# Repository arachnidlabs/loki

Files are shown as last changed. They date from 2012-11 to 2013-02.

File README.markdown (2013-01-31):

Loki
====

Loki is a flexible development platform based on Cypress's PSoC 5 line of processors.

For much more about Loki, check out the [Arachnid Labs Blog](http://www.arachnidlabs.com/)

All the Loki source and schematics are open hardware and OSS, and licensed under the [BSD 2-clause license](http://opensource.org/licenses/BSD-2-Clause). Reuse and remix as you see fit!

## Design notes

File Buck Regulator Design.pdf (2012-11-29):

## WEBENCH ® Design Report

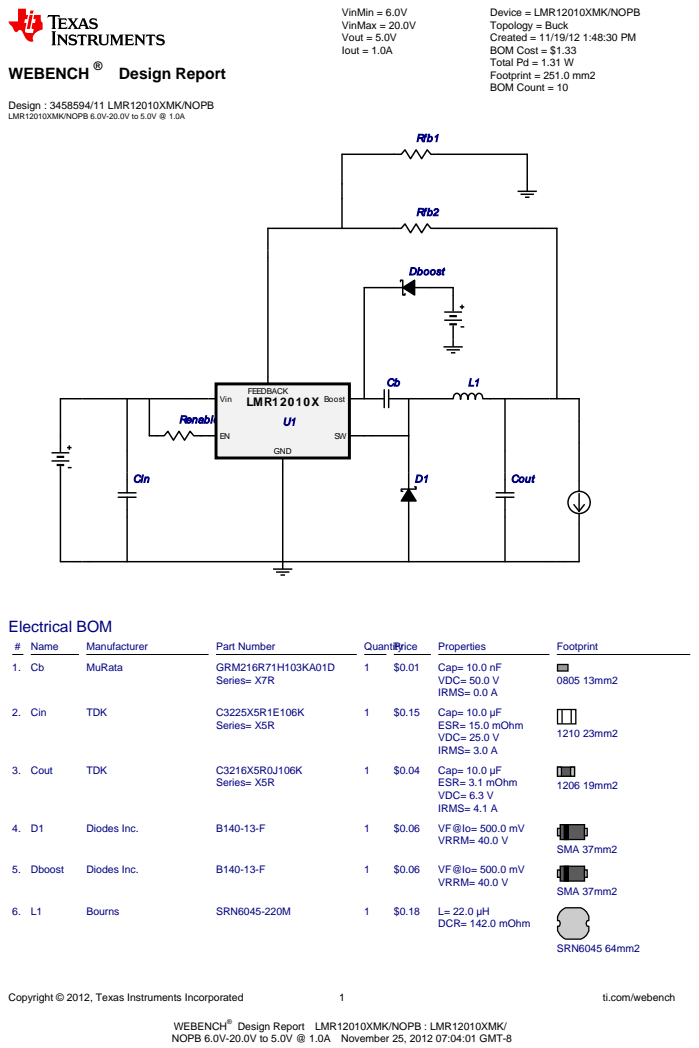
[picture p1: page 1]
Copyright © 2012, Texas Instruments Incorporated; ti.com/webench; Design : 3458594/11 LMR12010XMK/NOPB LMR12010XMK/NOPB 6.0V-20.0V to 5.0V @ 1.0A; VinMin = 6.0V VinMax = 20.0V Vout = 5.0V Iout = 1.0A; Device = LMR12010XMK/NOPB Topology = Buck Created = 11/19/12 1:48:30 PM BOM Cost = $1.33 Total Pd = 1.31 W Footprint = 251.0 mm2 BOM Count = 10; Cin; Cout; Dboost; Renable; LMR12010X; FEEDBACK; Vin; Boost; GND; Rfb1; Rfb2; Electrical BOM; # Name; Manufacturer; Part Number; QuantityPrice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

WEBENCH®
NOPB 6.0V-20.0V to 5.0V @ 1.0A November 25, 2012 07:04:01 GMT-8

Design Report LMR12010XMK/NOPB : LMR12010XMK/

Design

Copyright © 2012, Texas Instruments Incorporated | 2 | ti.com/webench
# Name | Manufacturer | Part Number | QuantityPrice | Properties | Footprint

7. Renable | Vishay-Dale | CRCW080510K0FKEA (http://www.vishay.com/docs/20035/dcrcwe3.pdf)
Series= CRCW..e3
1 | $0.01 | Res= 10.0 kOhm
Power= 125.0 mW
Tolerance= 1.0%

0805 13mm2

8. Rfb1 | Vishay-Dale | CRCW080510K0FKEA (http://www.vishay.com/docs/20035/dcrcwe3.pdf)
Series= CRCW..e3
1 | $0.01 | Res= 10.0 kOhm
Power= 125.0 mW
Tolerance= 1.0%

0805 13mm2

9. Rfb2 | Vishay-Dale | CRCW080552K3FKEA (http://www.vishay.com/docs/20035/dcrcwe3.pdf)
Series= CRCW..e3
1 | $0.01 | Res= 52.3 kOhm
Power= 125.0 mW
Tolerance= 1.0%

0805 13mm2

10. U1 | Texas Instruments | LMR12010XMK/NOPB (http://www.ti.com/product/lmr12010) | 1 | $0.80 | Switcher

MK06A 18mm2

## Operating Values

# | Name | Value | Category | Description

1. BOM Count | 10.0 | Total Design BOM count
2. Total BOM | $1.33 | Total BOM Cost
3. Cin IRMS | 444.634 m A | Current | Input capacitor RMS ripple current
4. Cout IRMS | 33.375 m A | Current | Output capacitor RMS ripple current
5. IC Ipk | 1.058 A | Current | Peak switch current in IC
6. Iin Avg | 315.61 m A | Current | Average input current
7. L Ipp | 115.614 m A | Current | Peak-to-peak inductor ripple current
8. M1 Irms | 520.872 m A | Current | Q Iavg
9. FootPrint | 251.0 mm2 | General | Total Foot Print Area of BOM components
10. Frequency | 1.6 M Hz | General | Switching frequency
11. IC Tolerance | 16.0 m V | General | IC Feedback Tolerance
12. M Vds Act | 227.775 m V | General
13. Mode | CCM | General | Conduction Mode
14. Pout | 5.0 W | General | Total output power
15. Duty Cycle | 27.131 % | Op_point | Duty cycle
16. Efficiency | 79.212 % | Op_point | Steady state efficiency
17. IC Tj | 123.059 degC | Op_point | IC junction temperature
18. ICThetaJA | 118.0 degC/W | Op_point | IC junction-to-ambient thermal resistance
19. IOUT_OP | 1.0 A | Op_point | Iout operating point
20. VIN_OP | 20.0 V | Op_point | Vin operating point
21. Vout p-p | 971.742 µ V | Op_point | Peak-to-peak output ripple voltage
22. Cin Pd | 2.965 m W | Power | Input capacitor power dissipation
23. Cout Pd | 3.453 µ W | Power | Output capacitor power dissipation
24. Diode Pd | 364.346 m W | Power | Diode power dissipation
25. IC Pd | 788.638 m W | Power | IC power dissipation
26. L Pd | 156.2 m W | Power | Inductor power dissipation
27. Total Pd | 1.312 W | Power | Total Power Dissipation

## Design Inputs

# | Name | Value | Description

1. Iout | 1.0 A | Maximum Output Current
2. Iout1 | 1.0 Amps | Output Current #1
3. VinMax | 20.0 V | Maximum input voltage
4. VinMin | 6.0 V | Minimum input voltage
5. Vout | 5.0 V | Output Voltage
6. Vout1 | 5.0 Volt | Output Voltage #1
7. base_pn | LMR12010X | National Based Product Number
8. Ta | 30.0 degC | Ambient temperature

## Design Assistance

1. LMR12010X Product Folder : http://www.ti.com/product/lmr12010 : contains the data sheet and other resources.

Design

Copyright © 2012, Texas Instruments Incorporated | 3 | ti.com/webench

Texas Instruments' WEBENCH simulation tools attempt to recreate the performance of a substantially equivalent physical implementation
of the design. Simulations are created using Texas Instruments' published specifications as well as the published specifications of other device manufacturers. While Texas Instruments does update this information periodically, this information may not be current at the time the simulation is built. Texas Instruments does not warrant the accuracy or completeness of the specifications or any information contained therein. Texas Instruments does not warrant that any designs or recommended parts will meet the specifications you entered, will be suitable for your application or fit for any particular purpose, or will operate as shown in the simulation in a physical implementation. Texas Instruments does not warrant that the designs are production worthy.
You should completely validate and test your design implementation to confirm the system functionality for your application prior to production.
Use of Texas Instruments' WEBENCH simulation tools is subject to Texas Instruments' Site Terms and Conditions of Use. (http://www.ti.com/corp/docs/legal/termsofuse.shtml) Prototype boards based on WEBENCH created designs are provided AS IS without warranty of any kind for evaluation and testing purposes and are subject to the terms of the Evaluation License Agreement. (http://www.ti.com/corp/docs/legal/termsofuse_estore.shtml)

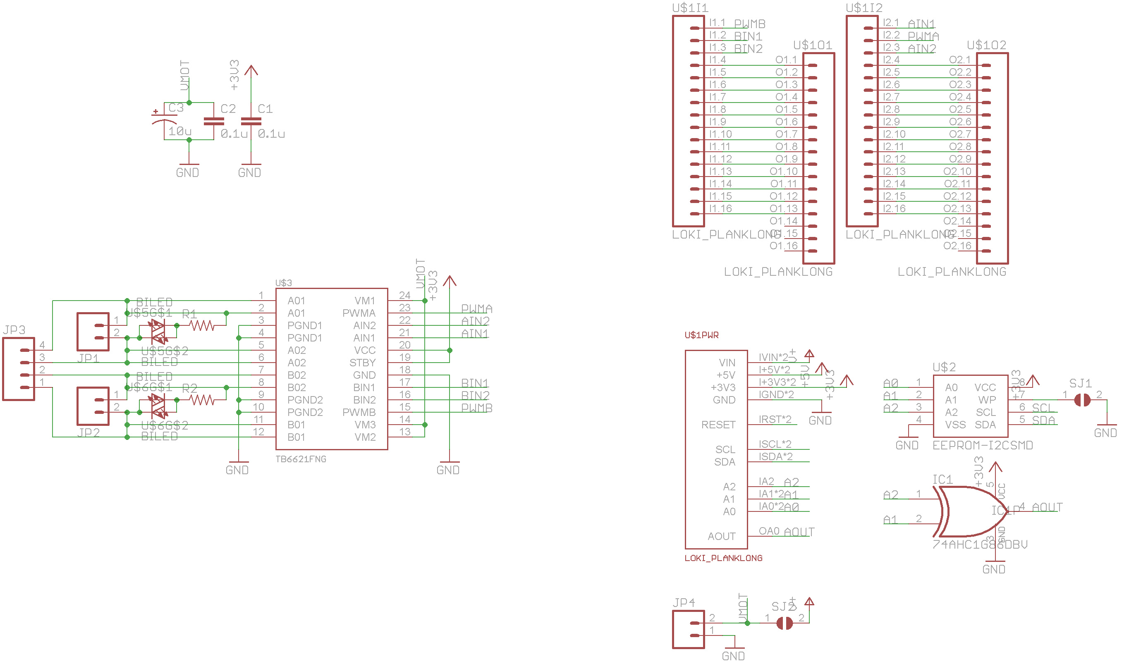
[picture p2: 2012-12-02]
schematics/motorplank/motorplank-schematic.png

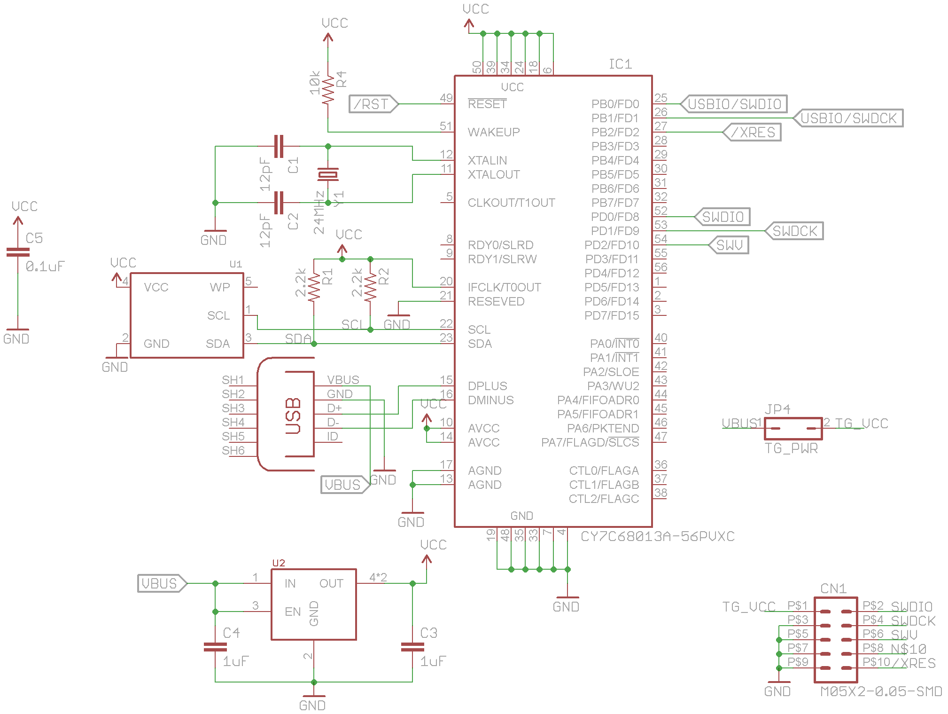
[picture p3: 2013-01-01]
schematics/programmer/programmer-schematic.png

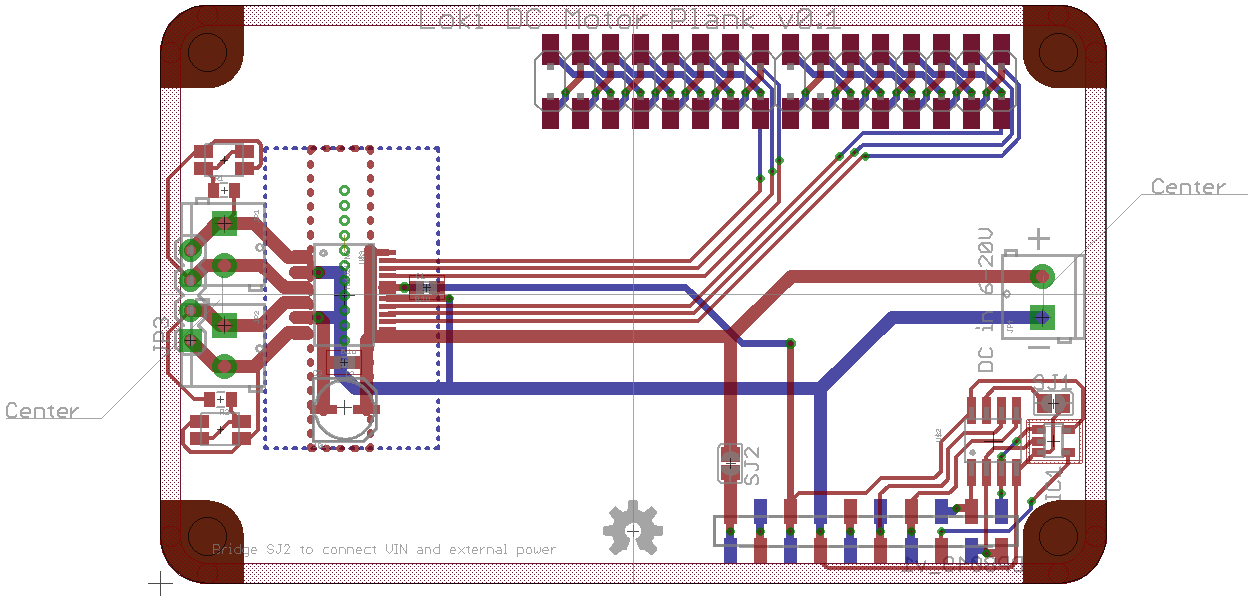
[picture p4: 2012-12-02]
schematics/motorplank/motorplank-layout.png

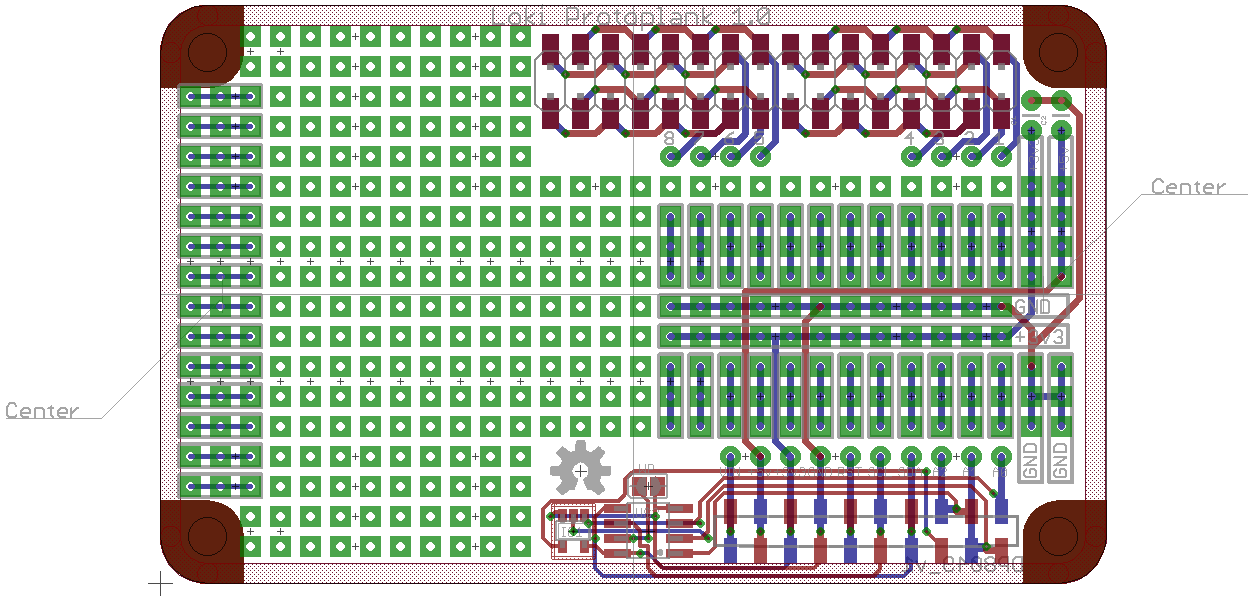
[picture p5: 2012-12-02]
schematics/protoplank/protoplank-layout.png

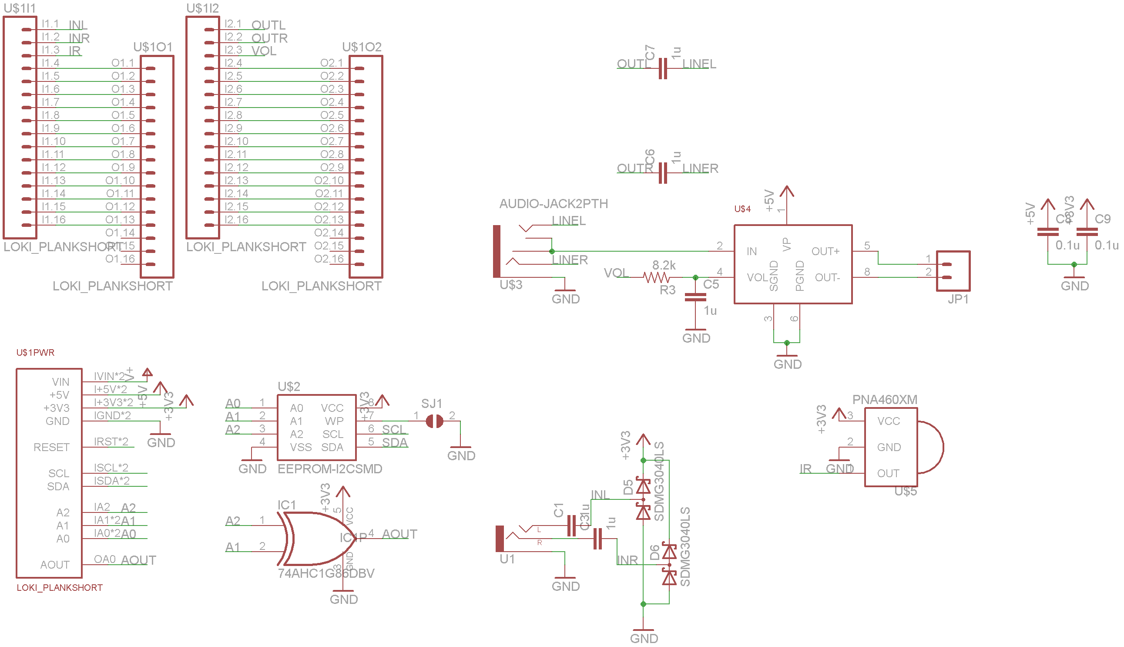
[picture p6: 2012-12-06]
schematics/soundplank/soundplank-schematic.png

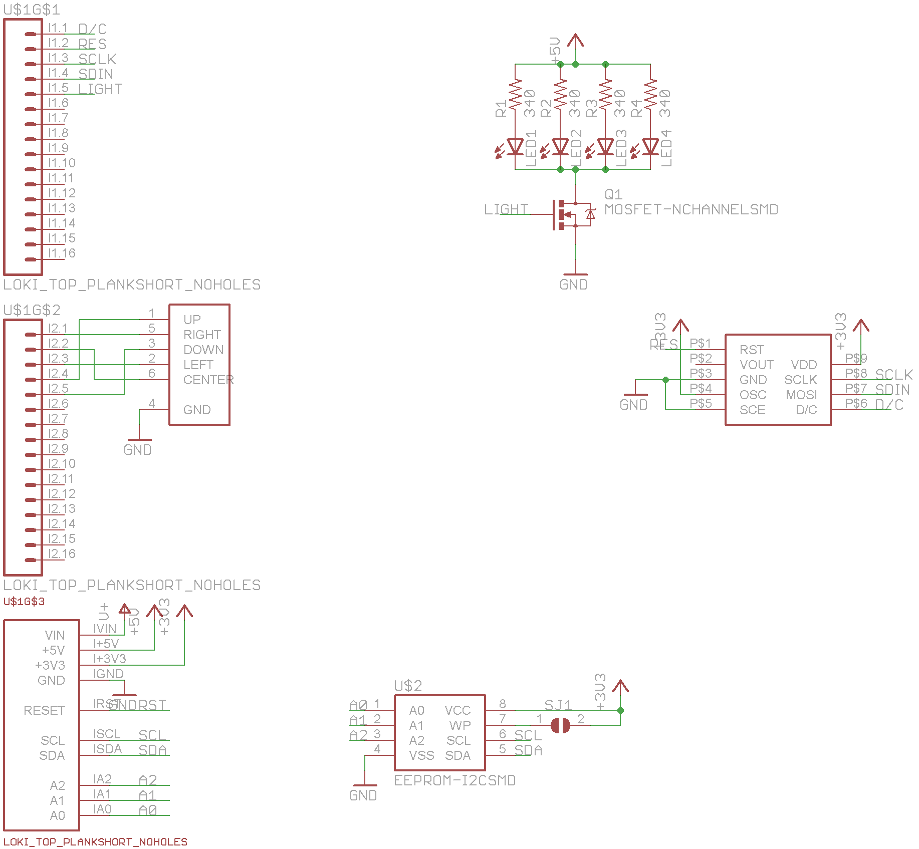
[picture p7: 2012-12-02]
schematics/displayplank/displayplank-schematic.png

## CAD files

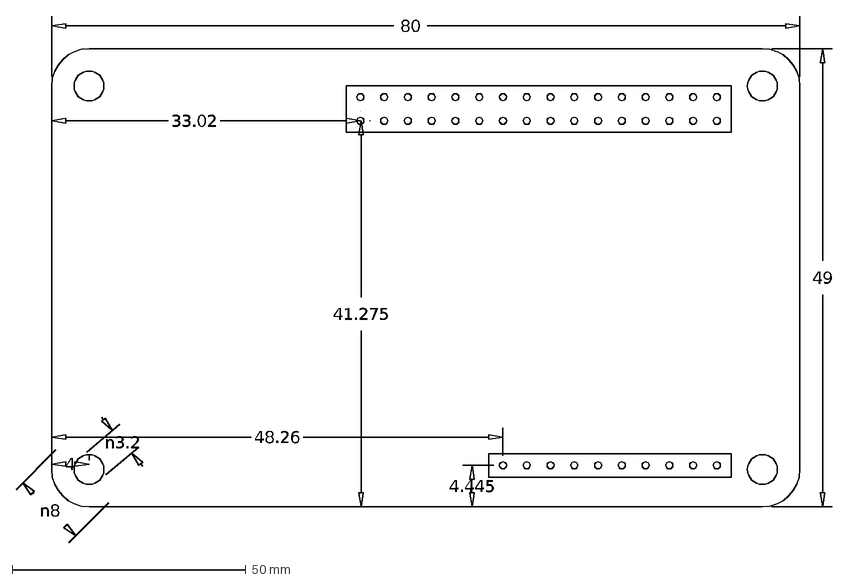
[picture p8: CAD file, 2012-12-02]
drawings/Dimensional Drawing.dxf
80
49
33.02
41.275
4.445
48.26
4

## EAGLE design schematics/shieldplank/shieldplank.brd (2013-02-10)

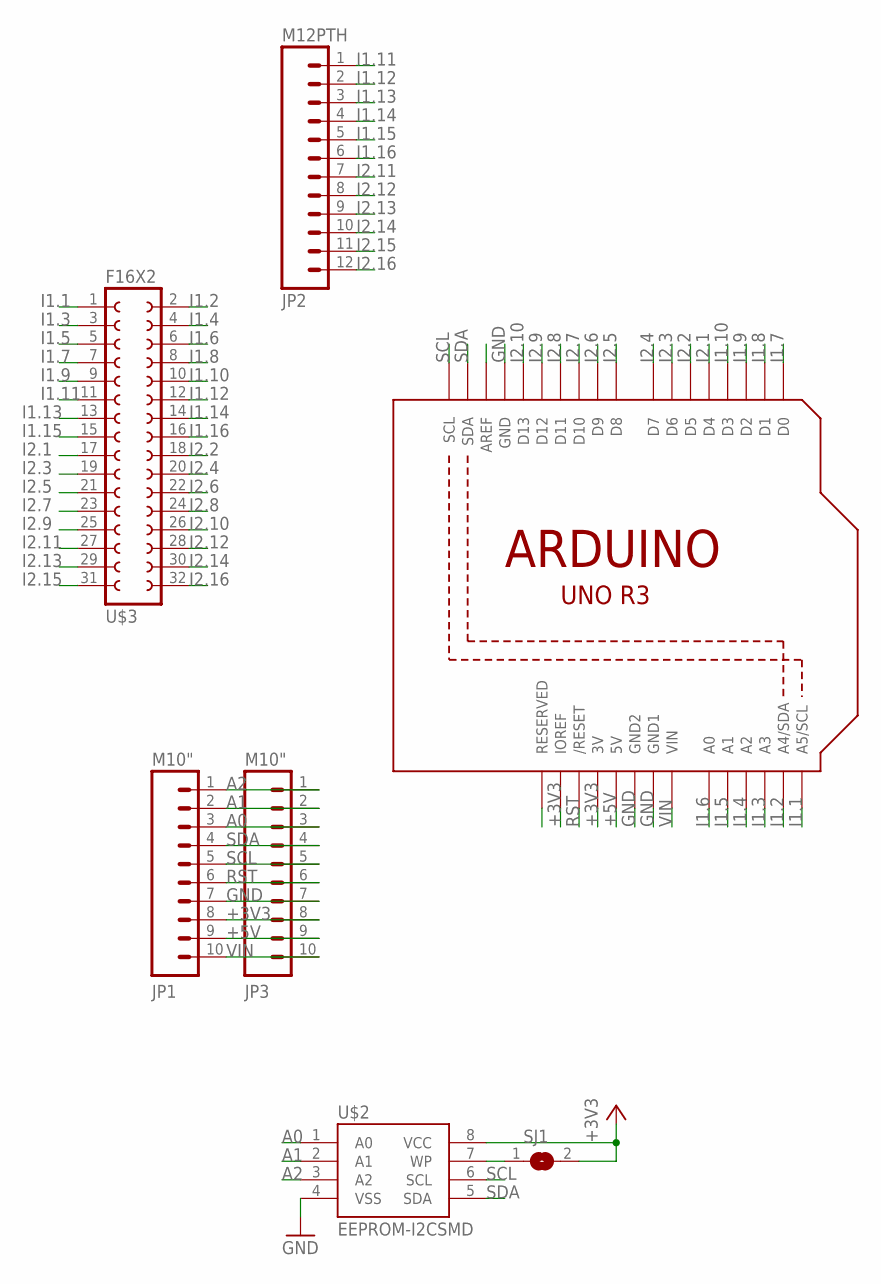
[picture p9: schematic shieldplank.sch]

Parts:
JP1, JP3: M10"; 1X10
JP2: M12PTH; 1X12
SJ1: SJ
U1: ARDUINOR3-BPLACE
U$2: EEPROM-I2CSMD; SO08
U$3: F16X2; FE16-2

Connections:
+3V3: JP1.8, JP3.8, SJ1.2, U1.3V, U1.IOREF, U$2.8 (VCC)
+5V: JP1.9, JP3.9, U1.5V
A0: JP1.3, JP3.3, U$2.1 (A0)
A1: JP1.2, JP3.2, U$2.2 (A1)
A2: JP1.1, JP3.1, U$2.3 (A2)
GND: JP1.7, JP3.7, U1.GND, U1.GND1, U1.GND2, U$2.4 (VSS)
I1.1: U1.A5 (A5/SCL), U$3.1
I1.2: U1.A4 (A4/SDA), U$3.2
I1.3: U1.A3, U$3.3
I1.4: U1.A2, U$3.4
I1.5: U1.A1, U$3.5
I1.6: U1.A0, U$3.6
I1.7: U1.D0, U$3.7
I1.8: U1.D1, U$3.8
I1.9: U1.D2, U$3.9
I1.10: U1.D3, U$3.10
I1.11: JP2.1, U$3.11
I1.12: JP2.2, U$3.12
I1.13: JP2.3, U$3.13
I1.14: JP2.4, U$3.14
I1.15: JP2.5, U$3.15
I1.16: JP2.6, U$3.16
I2.1: U1.D4, U$3.17
I2.2: U1.D5, U$3.18
I2.3: U1.D6, U$3.19
I2.4: U1.D7, U$3.20
I2.5: U1.D8, U$3.21
I2.6: U1.D9, U$3.22
I2.7: U1.D10, U$3.23
I2.8: U1.D11, U$3.24
I2.9: U1.D12, U$3.25
I2.10: U1.D13, U$3.26
I2.11: JP2.7, U$3.27
I2.12: JP2.8, U$3.28
I2.13: JP2.9, U$3.29
I2.14: JP2.10, U$3.30
I2.15: JP2.11, U$3.31
I2.16: JP2.12, U$3.32
unnamed: SJ1.1, U$2.7 (WP)
RST: JP1.6, JP3.6, U1.RESET (/RESET)
SCL: JP1.5, JP3.5, U1.SCL, U$2.6 (SCL)
SDA: JP1.4, JP3.4, U1.SDA, U$2.5 (SDA)
VIN: JP1.10, JP3.10, U1.VIN

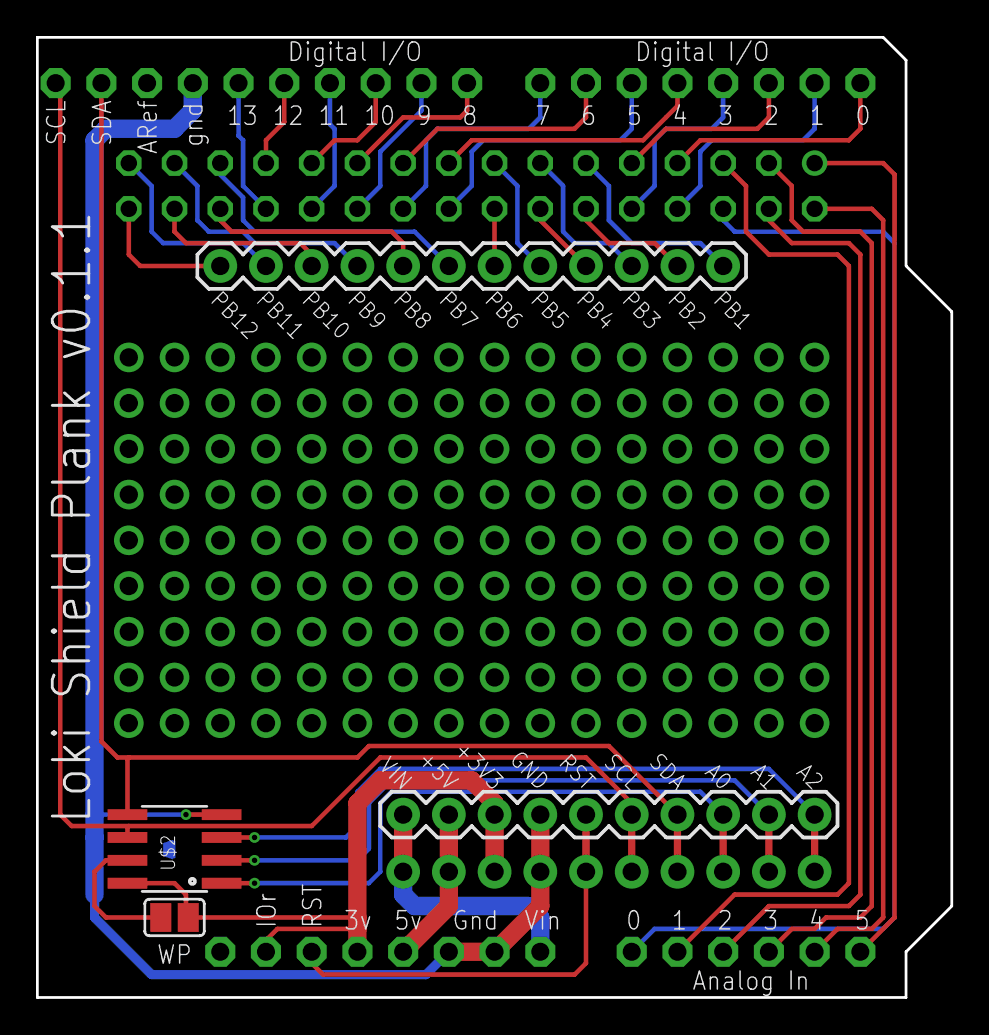
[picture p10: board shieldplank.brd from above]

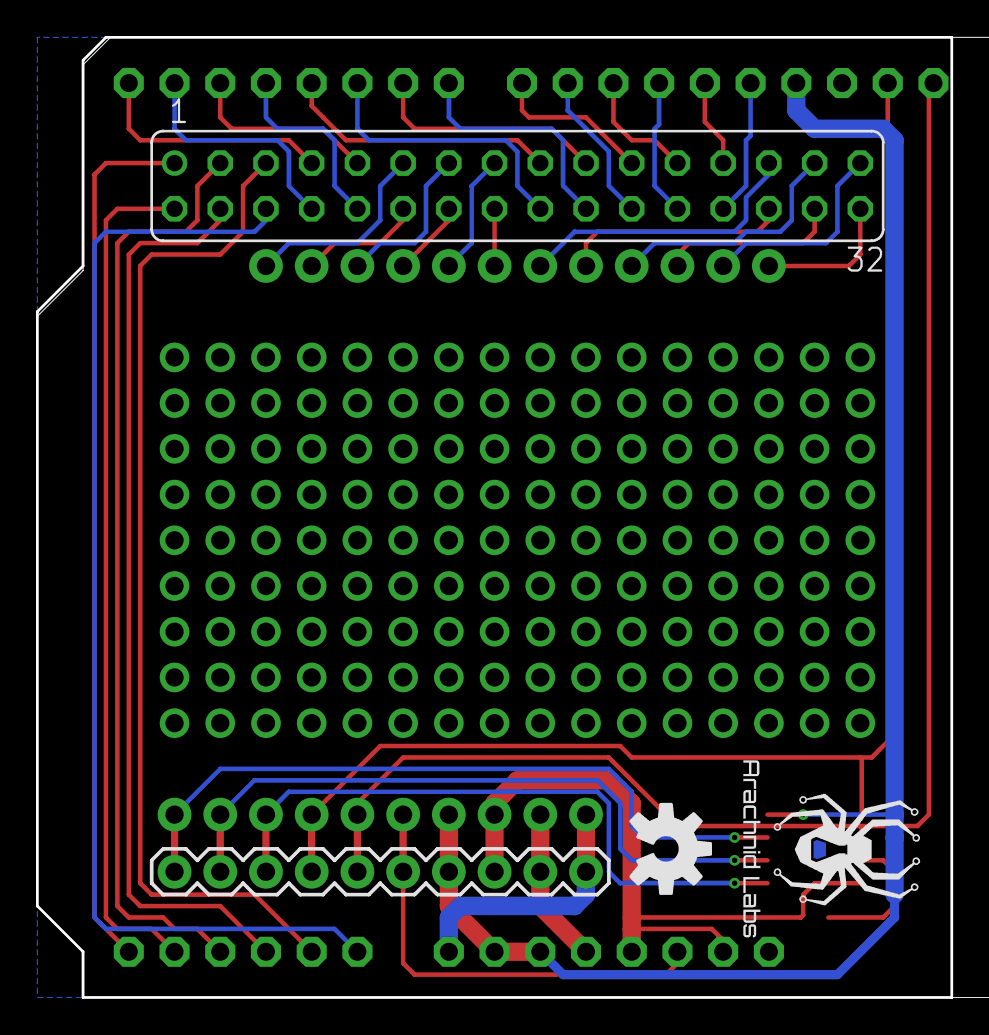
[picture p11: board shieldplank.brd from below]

Board: 2 copper layers, 50.8 x 53.3 mm, 9 parts (4 on the bottom side), 43 nets.

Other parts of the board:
U$1: ARACHNID_LABS_LOGO_SM
U$4: OSHW-LOGO-M

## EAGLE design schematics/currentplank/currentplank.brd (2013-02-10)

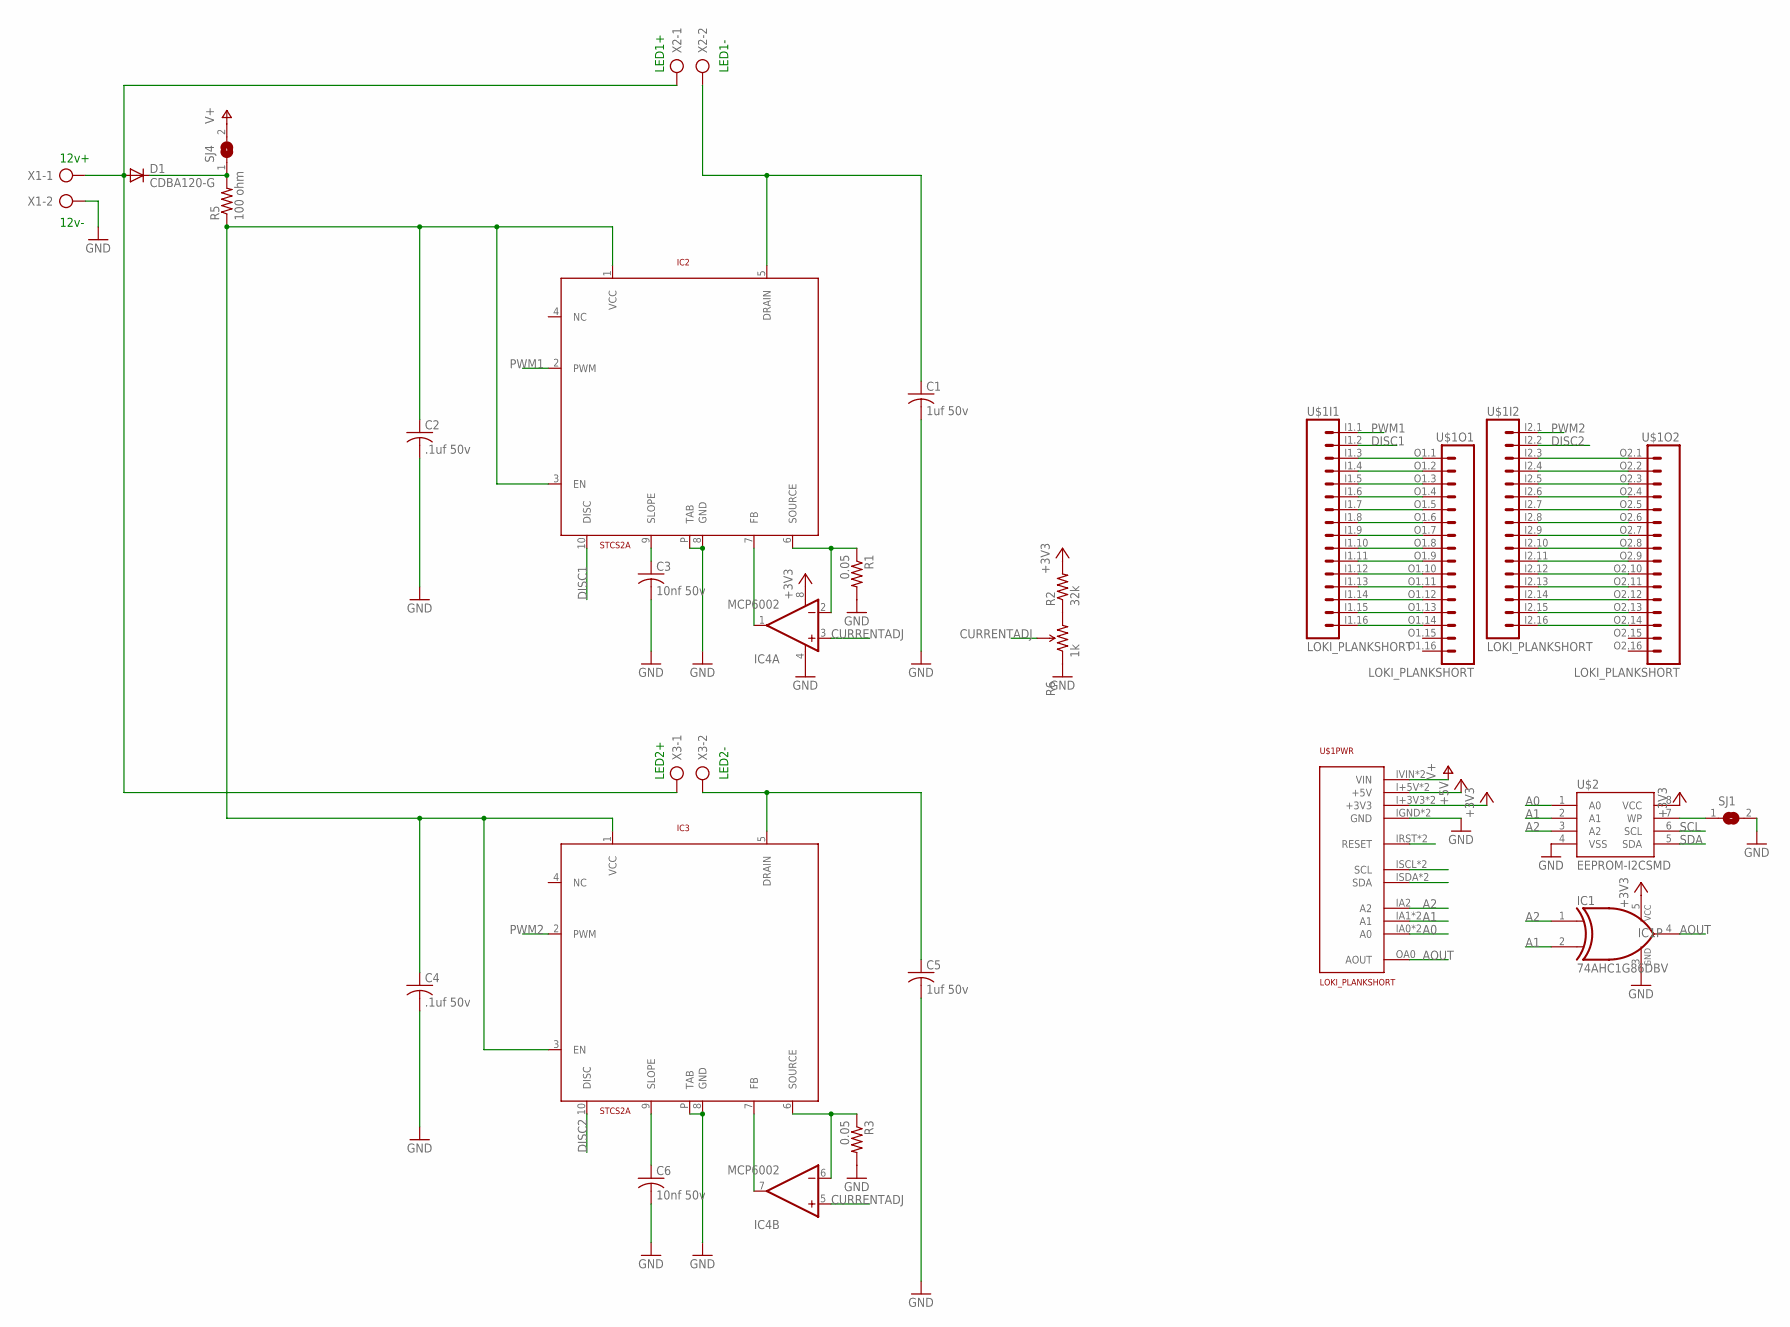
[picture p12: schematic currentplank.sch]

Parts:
C1, C5: 1uf 50v; C0805
C2, C4: .1uf 50v; C0805
C3, C6: 10nf 50v; C0805
D1: CDBA120-G; SMA-DIODE
IC1: 74AHC1G86DBV; SOT23-5
IC2, IC3: STCS2A; STCS2A_POWER-SO10
IC4: MCP6002; SO08
R1, R3: 0.05; 1206
R2: 32k; 0805
R5: 100 ohm; 0805
R6: 1k; TRIMPOT-3MM-2
SJ1, SJ4: SJ
U$1: LOKI_PLANKSHORT; PLANK_SHORT
U$2: EEPROM-I2CSMD; SO08
X1, X2, X3: AK500/2-H

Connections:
+3V3: IC1.5 (VCC), IC4.8 (V+), R2.2, U$1.I+3V3 (+3V3), U$1.O+3V3 (+3V3), U$2.8 (VCC)
+5V: U$1.I+5V (+5V), U$1.O+5V (+5V)
A0: U$1.IA0 (A0), U$1.OA1 (A0), U$2.1 (A0)
A1: IC1.2 (I1), U$1.IA1 (A1), U$1.OA2 (A1), U$2.2 (A1)
A2: IC1.1 (I0), U$1.IA2 (A2), U$2.3 (A2)
AOUT: IC1.4 (O), U$1.OA0 (AOUT)
CURRENTADJ: IC4.3 (+IN), IC4.5 (+IN), R6.2 (WIPER)
DISC1: IC2.10 (DISC), U$1.I1.2 (2)
DISC2: IC3.10 (DISC), U$1.I2.2 (2)
GND: C1.2, C2.2, C3.2, C4.2, C5.2, C6.2, IC1.3 (GND), IC2.8 (GND), IC2.P (TAB), IC3.8 (GND), IC3.P (TAB), IC4.4 (V-), R1.2, R3.2, R6.1 (CCW), SJ1.2, U$1.IGND (GND), U$1.OGND (GND), U$2.4 (VSS), X1.2
unnamed: U$1.I1.16 (16), U$1.O1.14 (14)
unnamed: U$1.I1.15 (15), U$1.O1.13 (13)
unnamed: U$1.I1.14 (14), U$1.O1.12 (12)
unnamed: U$1.I1.13 (13), U$1.O1.11 (11)
unnamed: U$1.I1.12 (12), U$1.O1.10 (10)
unnamed: U$1.I1.11 (11), U$1.O1.9 (9)
unnamed: U$1.I1.10 (10), U$1.O1.8 (8)
unnamed: U$1.I1.9 (9), U$1.O1.7 (7)
unnamed: U$1.I1.8 (8), U$1.O1.6 (6)
unnamed: U$1.I1.7 (7), U$1.O1.5 (5)
unnamed: U$1.I1.6 (6), U$1.O1.4 (4)
unnamed: U$1.I1.5 (5), U$1.O1.3 (3)
unnamed: U$1.I1.4 (4), U$1.O1.2 (2)
unnamed: U$1.I1.3 (3), U$1.O1.1 (1)
unnamed: U$1.I2.16 (16), U$1.O2.14 (14)
unnamed: U$1.I2.15 (15), U$1.O2.13 (13)
unnamed: U$1.I2.14 (14), U$1.O2.12 (12)
unnamed: U$1.I2.13 (13), U$1.O2.11 (11)
unnamed: U$1.I2.12 (12), U$1.O2.10 (10)
unnamed: U$1.I2.11 (11), U$1.O2.9 (9)
unnamed: U$1.I2.10 (10), U$1.O2.8 (8)
unnamed: U$1.I2.9 (9), U$1.O2.7 (7)
unnamed: U$1.I2.8 (8), U$1.O2.6 (6)
unnamed: U$1.I2.7 (7), U$1.O2.5 (5)
unnamed: U$1.I2.6 (6), U$1.O2.4 (4)
unnamed: U$1.I2.5 (5), U$1.O2.3 (3)
unnamed: U$1.I2.4 (4), U$1.O2.2 (2)
unnamed: U$1.I2.3 (3), U$1.O2.1 (1)
unnamed: IC2.6 (SOURCE), IC4.2 (-IN), R1.1
unnamed: IC2.7 (FB), IC4.1 (OUT)
unnamed: SJ1.1, U$2.7 (WP)
unnamed: U$1.IRST (RESET), U$1.ORST (RESET)
unnamed: D1.C, R5.2, SJ4.1
unnamed: C3.1, IC2.9 (SLOPE)
unnamed: D1.A, X1.1, X2.1, X3.1
unnamed: C1.1, IC2.5 (DRAIN), X2.2
unnamed: C5.1, IC3.5 (DRAIN), X3.2
unnamed: C6.1, IC3.9 (SLOPE)
unnamed: IC3.6 (SOURCE), IC4.6 (-IN), R3.1
unnamed: IC3.7 (FB), IC4.7 (OUT)
unnamed: R2.1, R6.3 (CW)
unnamed: C2.1, C4.1, IC2.1 (VCC), IC2.3 (EN), IC3.1 (VCC), IC3.3 (EN), R5.1
PWM1: IC2.2 (PWM), U$1.I1.1 (1)
PWM2: IC3.2 (PWM), U$1.I2.1 (1)
SCL: U$1.ISCL (SCL), U$1.OSCL (SCL), U$2.6 (SCL)
SDA: U$1.ISDA (SDA), U$1.OSDA (SDA), U$2.5 (SDA)
V+: SJ4.2, U$1.IVIN (VIN), U$1.OVIN (VIN)

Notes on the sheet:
12v+
12v-
LED1+
LED1-
LED2-
LED2+

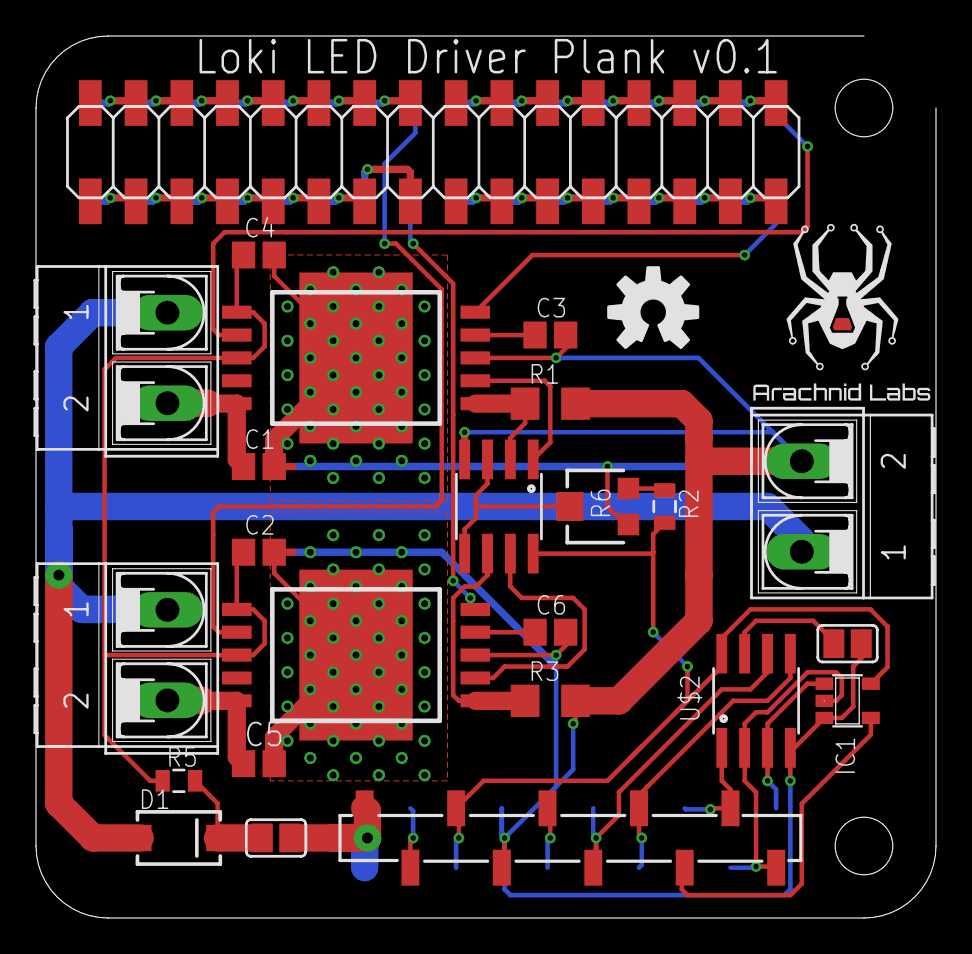
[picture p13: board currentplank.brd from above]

Board: 2 copper layers, 50.0 x 49.0 mm, 25 parts (0 on the bottom side), 57 nets.

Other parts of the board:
U$3: OSHW-LOGO-M
U$4: ARACHNID_LABS_LOGO_SM

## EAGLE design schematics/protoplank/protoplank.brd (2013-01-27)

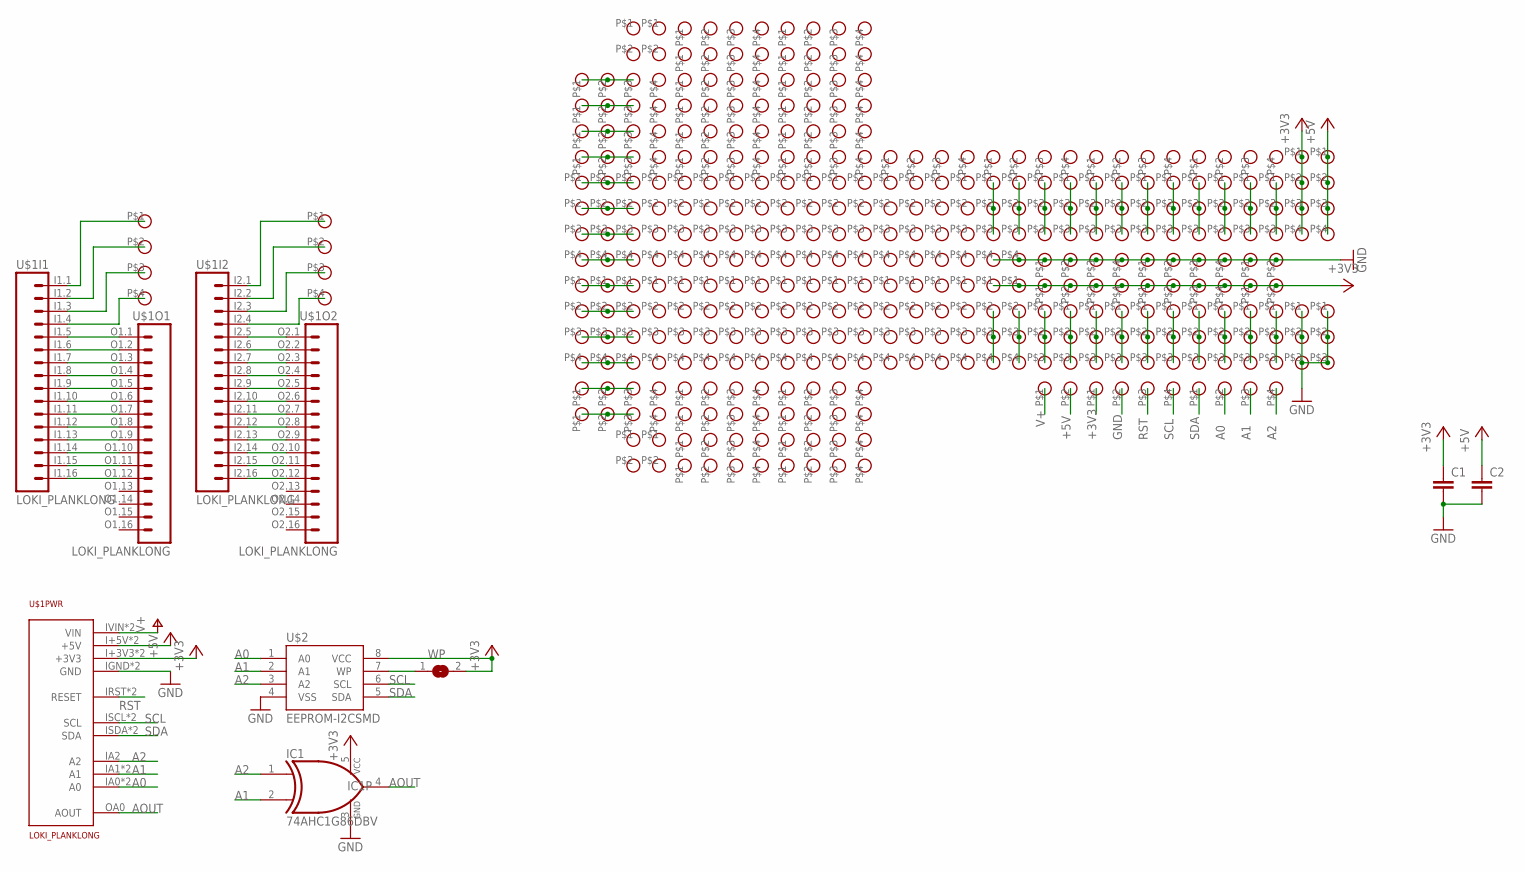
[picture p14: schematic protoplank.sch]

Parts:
C1, C2: CAPPTH; CAP-PTH-SMALL
IC1: 74AHC1G86DBV; SOT23-5
U$1: LOKI_PLANKLONG; PLANK_LONG
U$2: EEPROM-I2CSMD; SO08
U$3, U$4, U$5, U$6, U$7, U$8, U$9, U$10, U$11, U$12, U$13, U$14, U$15, U$16, U$17, U$18, U$19, U$20, U$21, U$22, U$78, U$80: PROTOPAD-3
U$23, U$24, U$25, U$26, U$34, U$35, U$36, U$37, U$38, U$39, U$40, U$41, U$42, U$43, U$44, U$45, U$46, U$47, U$48, U$49, U$50, U$51, U$52, U$53, U$54, U$55, U$56, U$57, U$58, U$59, U$60, U$61, U$62, U$63, U$64, U$65, U$66, U$67, U$68, U$69, U$70, U$71, U$72, U$73, U$74, U$75, U$76, U$77, U$79, U$81, U$82, U$83, U$84, U$85, U$86, U$87, U$88, U$89, U$90, U$91, U$92, U$93, U$94, U$95, U$96, U$97, U$98, U$99, U$100, U$101, U$102, U$103: PROTOPAD-4SQUARE; PROTOPAD-4
U$27, U$28, U$104, U$105, U$106, U$107: PROTOPAD-2SQUARE; PROTOPAD-2
U$29, U$30, U$31, U$32: PROTOPAD-4ROUND; PROTOPAD-4-ROUND
U$33: PROTOPAD-2ROUND; PROTOPAD-2-ROUND
WP: SJ

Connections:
+3V3: C1.1, IC1.5 (VCC), U$1.I+3V3 (+3V3), U$1.O+3V3 (+3V3), U$2.8 (VCC), U$25.P$1, U$25.P$2, U$25.P$3, U$25.P$4, U$26.P$1, U$26.P$2, U$26.P$3, U$26.P$4, U$28.P$1, U$28.P$2, U$32.P$1, U$35.P$1, U$36.P$1, U$77.P$1, U$77.P$2, U$77.P$3, U$77.P$4, WP.2
+5V: C2.1, U$1.I+5V (+5V), U$1.O+5V (+5V), U$33.P$2, U$79.P$1, U$79.P$2, U$79.P$3, U$79.P$4
A0: U$1.IA0 (A0), U$1.OA1 (A0), U$2.1 (A0), U$31.P$2
A1: IC1.2 (I1), U$1.IA1 (A1), U$1.OA2 (A1), U$2.2 (A1), U$31.P$3
A2: IC1.1 (I0), U$1.IA2 (A2), U$2.3 (A2), U$31.P$4
AOUT: IC1.4 (O), U$1.OA0 (AOUT)
GND: C1.2, C2.2, IC1.3 (GND), U$1.IGND (GND), U$1.OGND (GND), U$2.4 (VSS), U$23.P$1, U$23.P$2, U$23.P$3, U$23.P$4, U$24.P$1, U$24.P$2, U$24.P$3, U$24.P$4, U$27.P$1, U$27.P$2, U$32.P$2, U$34.P$4, U$37.P$4, U$78.P$1, U$78.P$2, U$78.P$3, U$80.P$1, U$80.P$2, U$80.P$3
unnamed: U$1.I1.16 (16), U$1.O1.12 (12)
unnamed: U$1.I1.15 (15), U$1.O1.11 (11)
unnamed: U$1.I1.14 (14), U$1.O1.10 (10)
unnamed: U$1.I1.13 (13), U$1.O1.9 (9)
unnamed: U$1.I1.12 (12), U$1.O1.8 (8)
unnamed: U$1.I1.11 (11), U$1.O1.7 (7)
unnamed: U$1.I1.10 (10), U$1.O1.6 (6)
unnamed: U$1.I1.9 (9), U$1.O1.5 (5)
unnamed: U$1.I1.8 (8), U$1.O1.4 (4)
unnamed: U$1.I1.7 (7), U$1.O1.3 (3)
unnamed: U$1.I1.6 (6), U$1.O1.2 (2)
unnamed: U$1.I1.5 (5), U$1.O1.1 (1)
unnamed: U$1.I2.16 (16), U$1.O2.12 (12)
unnamed: U$1.I2.15 (15), U$1.O2.11 (11)
unnamed: U$1.I2.14 (14), U$1.O2.10 (10)
unnamed: U$1.I2.13 (13), U$1.O2.9 (9)
unnamed: U$1.I2.12 (12), U$1.O2.8 (8)
unnamed: U$1.I2.11 (11), U$1.O2.7 (7)
unnamed: U$1.I2.10 (10), U$1.O2.6 (6)
unnamed: U$1.I2.9 (9), U$1.O2.5 (5)
unnamed: U$1.I2.8 (8), U$1.O2.4 (4)
unnamed: U$1.I2.7 (7), U$1.O2.3 (3)
unnamed: U$1.I2.6 (6), U$1.O2.2 (2)
unnamed: U$1.I2.5 (5), U$1.O2.1 (1)
unnamed: U$1.I1.4 (4), U$29.P$4
unnamed: U$1.I1.3 (3), U$29.P$3
unnamed: U$1.I1.2 (2), U$29.P$2
unnamed: U$1.I1.1 (1), U$29.P$1
unnamed: U$1.I2.4 (4), U$30.P$4
unnamed: U$1.I2.3 (3), U$30.P$3
unnamed: U$2.7 (WP), WP.1
unnamed: U$3.P$1, U$3.P$2, U$3.P$3
unnamed: U$1.I2.2 (2), U$30.P$2
unnamed: U$1.I2.1 (1), U$30.P$1
unnamed: U$4.P$1, U$4.P$2, U$4.P$3
unnamed: U$5.P$1, U$5.P$2, U$5.P$3
unnamed: U$6.P$1, U$6.P$2, U$6.P$3
unnamed: U$7.P$1, U$7.P$2, U$7.P$3
unnamed: U$8.P$1, U$8.P$2, U$8.P$3
unnamed: U$9.P$1, U$9.P$2, U$9.P$3
unnamed: U$10.P$1, U$10.P$2, U$10.P$3
unnamed: U$11.P$1, U$11.P$2, U$11.P$3
unnamed: U$12.P$1, U$12.P$2, U$12.P$3
unnamed: U$13.P$1, U$13.P$2, U$13.P$3
unnamed: U$14.P$1, U$14.P$2, U$14.P$3
unnamed: U$15.P$1, U$15.P$2, U$15.P$3
unnamed: U$16.P$1, U$16.P$2, U$16.P$3
unnamed: U$17.P$1, U$17.P$2, U$17.P$3
unnamed: U$18.P$1, U$18.P$2, U$18.P$3
unnamed: U$19.P$1, U$19.P$2, U$19.P$3
unnamed: U$20.P$1, U$20.P$2, U$20.P$3
unnamed: U$21.P$1, U$21.P$2, U$21.P$3
unnamed: U$22.P$1, U$22.P$2, U$22.P$3
unnamed: U$89.P$1, U$89.P$2, U$89.P$3
unnamed: U$88.P$1, U$88.P$2, U$88.P$3
unnamed: U$34.P$1, U$34.P$2, U$34.P$3
unnamed: U$37.P$1, U$37.P$2, U$37.P$3
unnamed: U$81.P$1, U$81.P$2, U$81.P$3
unnamed: U$35.P$2, U$35.P$3, U$35.P$4
unnamed: U$36.P$2, U$36.P$3, U$36.P$4
unnamed: U$76.P$1, U$76.P$2, U$76.P$3
unnamed: U$65.P$1, U$66.P$1, U$69.P$1
unnamed: U$65.P$2, U$66.P$2, U$69.P$2
unnamed: U$65.P$3, U$66.P$3, U$69.P$3
unnamed: U$65.P$4, U$66.P$4, U$69.P$4
unnamed: U$64.P$1, U$67.P$1, U$68.P$1
unnamed: U$64.P$2, U$67.P$2, U$68.P$2
unnamed: U$64.P$3, U$67.P$3, U$68.P$3
unnamed: U$64.P$4, U$67.P$4, U$68.P$4
unnamed: U$96.P$1, U$96.P$2, U$96.P$3
unnamed: U$99.P$1, U$99.P$2, U$99.P$3
RST: U$1.IRST (RESET), U$1.ORST (RESET), U$32.P$3
SCL: U$1.ISCL (SCL), U$1.OSCL (SCL), U$2.6 (SCL), U$32.P$4
SDA: U$1.ISDA (SDA), U$1.OSDA (SDA), U$2.5 (SDA), U$31.P$1
V+: U$1.IVIN (VIN), U$1.OVIN (VIN), U$33.P$1

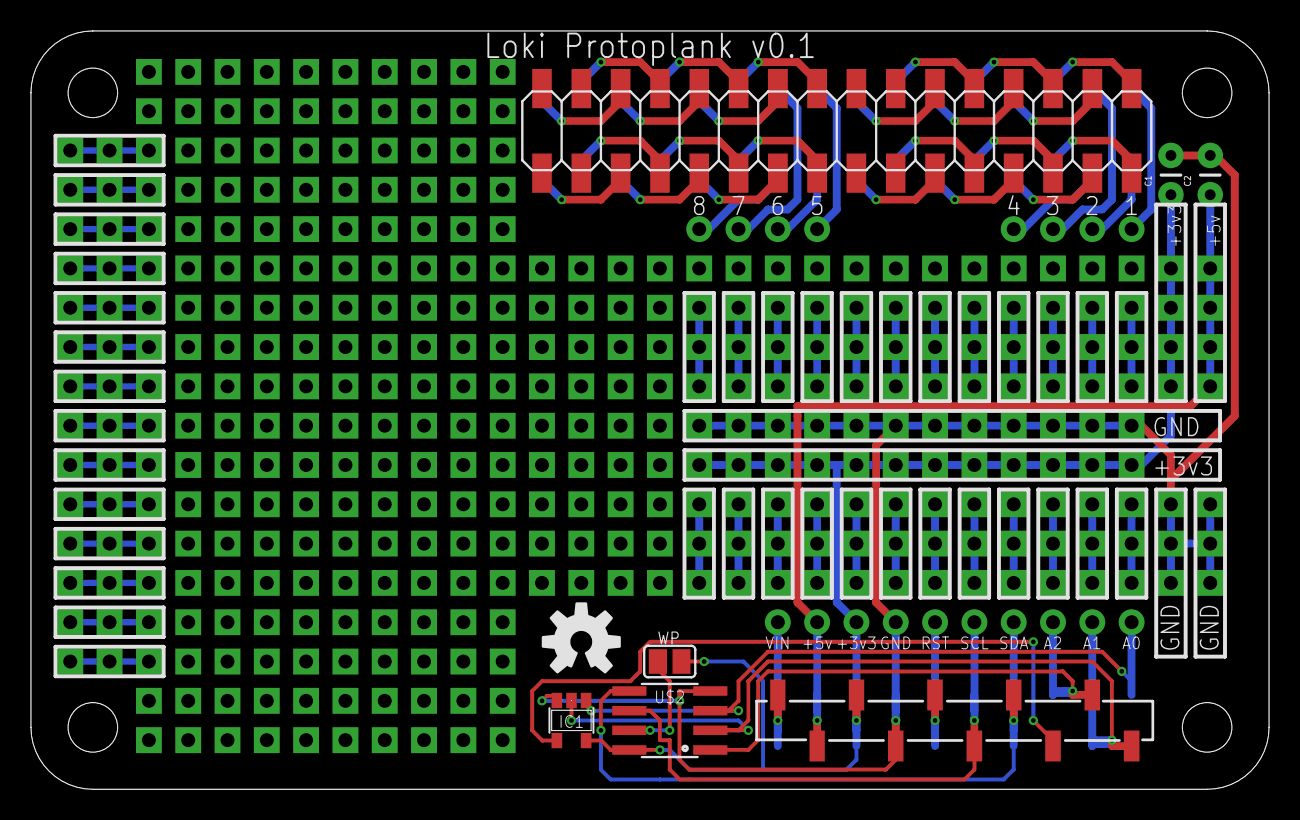
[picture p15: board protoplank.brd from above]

Board: 2 copper layers, 80.0 x 49.0 mm, 112 parts (0 on the bottom side), 82 nets.

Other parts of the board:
U$108: OSHW-LOGO-M

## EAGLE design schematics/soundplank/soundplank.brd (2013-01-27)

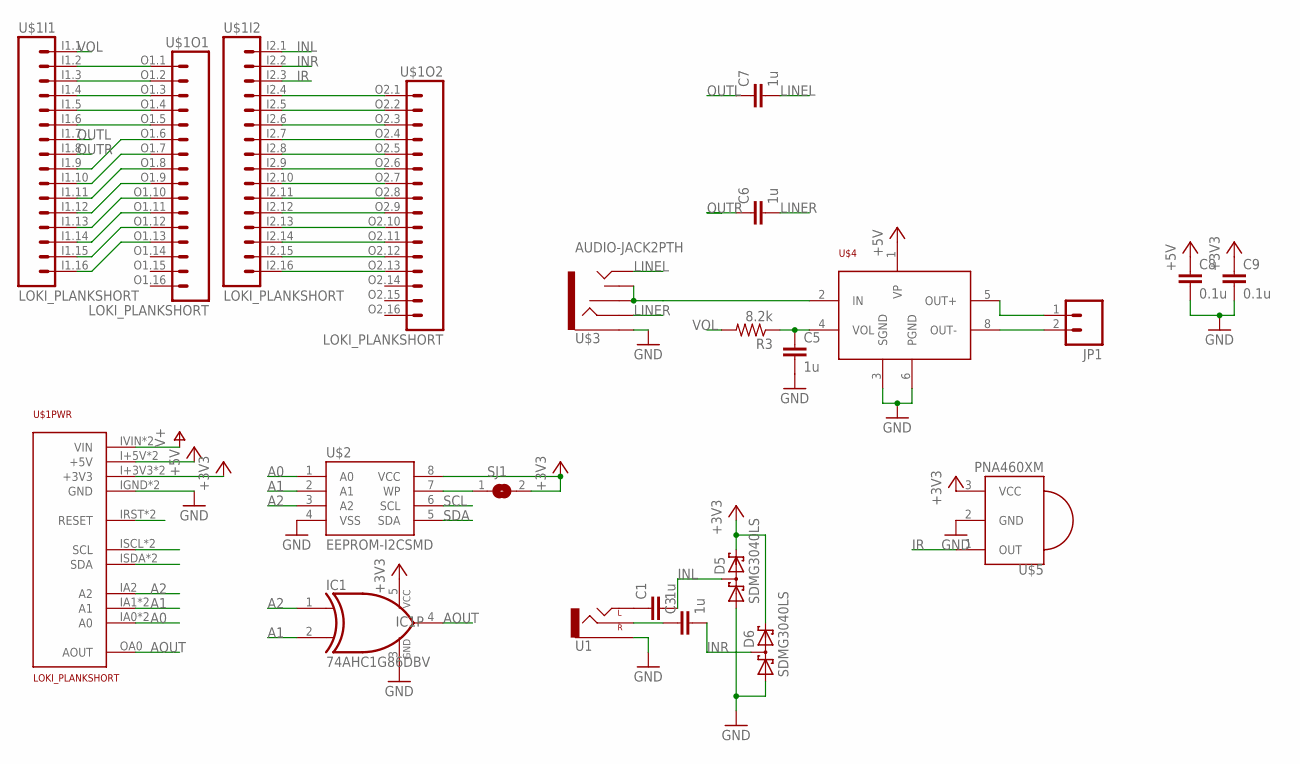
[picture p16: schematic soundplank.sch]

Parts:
C1, C3, C6, C7: 1u; 1210
C5: 1u; 0805
C8, C9: 0.1u; 0805
D5, D6: SDMG3040LS; SOT23
IC1: 74AHC1G86DBV; SOT23-5
JP1: M023.5MM; SCREWTERMINAL-3.5MM-2
R3: 8.2k; 0805
SJ1: SJ
U1: AUDIO-JACKPTH; AUDIO-JACK
U$1: LOKI_PLANKSHORT; PLANK_SHORT
U$2: EEPROM-I2CSMD; SO08
U$3: AUDIO-JACK2PTH; AUDIO-JACK
U$4: TDA7052A; SO08-MAX6675
U$5: PNA460XM

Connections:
+3V3: C9.1, D5.2 (C2), D6.2 (C2), IC1.5 (VCC), SJ1.2, U$1.I+3V3 (+3V3), U$1.O+3V3 (+3V3), U$2.8 (VCC), U$5.3 (VCC)
+5V: C8.1, U$1.I+5V (+5V), U$1.O+5V (+5V), U$4.1 (VP)
A0: U$1.IA0 (A0), U$1.OA1 (A0), U$2.1 (A0)
A1: IC1.2 (I1), U$1.IA1 (A1), U$1.OA2 (A1), U$2.2 (A1)
A2: IC1.1 (I0), U$1.IA2 (A2), U$2.3 (A2)
AOUT: IC1.4 (O), U$1.OA0 (AOUT)
GND: C5.2, C8.2, C9.2, D5.1 (A1), D6.1 (A1), IC1.3 (GND), U1.SLEEVE, U$1.IGND (GND), U$1.OGND (GND), U$2.4 (VSS), U$3.SLEEVE, U$4.3 (SGND), U$4.6 (PGND), U$5.2 (GND)
INL: C1.2, D5.3 (C1A2), U$1.I2.1 (1)
INR: C3.2, D6.3 (C1A2), U$1.I2.2 (2)
IR: U$1.I2.3 (3), U$5.1 (OUT)
LINEL: C7.2, U$3.TIP
LINER: C6.2, U$3.RING
unnamed: U$1.I1.2 (2), U$1.O1.1 (1)
unnamed: U$1.I1.3 (3), U$1.O1.2 (2)
unnamed: U$1.I1.4 (4), U$1.O1.3 (3)
unnamed: U$1.I1.5 (5), U$1.O1.4 (4)
unnamed: U$1.I1.6 (6), U$1.O1.5 (5)
unnamed: U$1.I1.9 (9), U$1.O1.6 (6)
unnamed: U$1.I1.10 (10), U$1.O1.7 (7)
unnamed: U$1.I1.11 (11), U$1.O1.8 (8)
unnamed: U$1.I1.12 (12), U$1.O1.9 (9)
unnamed: U$1.I1.13 (13), U$1.O1.10 (10)
unnamed: U$1.I1.14 (14), U$1.O1.11 (11)
unnamed: U$1.I1.15 (15), U$1.O1.12 (12)
unnamed: U$1.I1.16 (16), U$1.O1.13 (13)
unnamed: U$1.I2.16 (16), U$1.O2.13 (13)
unnamed: U$1.I2.15 (15), U$1.O2.12 (12)
unnamed: U$1.I2.14 (14), U$1.O2.11 (11)
unnamed: U$1.I2.13 (13), U$1.O2.10 (10)
unnamed: U$1.I2.12 (12), U$1.O2.9 (9)
unnamed: U$1.I2.11 (11), U$1.O2.8 (8)
unnamed: U$1.I2.10 (10), U$1.O2.7 (7)
unnamed: U$1.I2.9 (9), U$1.O2.6 (6)
unnamed: U$1.I2.8 (8), U$1.O2.5 (5)
unnamed: U$1.I2.7 (7), U$1.O2.4 (4)
unnamed: U$1.I2.6 (6), U$1.O2.3 (3)
unnamed: U$1.I2.5 (5), U$1.O2.2 (2)
unnamed: U$1.I2.4 (4), U$1.O2.1 (1)
unnamed: C5.1, R3.1, U$4.4 (VOL)
unnamed: JP1.2, U$4.8 (OUT-)
unnamed: SJ1.1, U$2.7 (WP)
unnamed: U$1.IRST (RESET), U$1.ORST (RESET)
unnamed: JP1.1, U$4.5 (OUT+)
unnamed: C1.1, U1.TIP (LEFT)
unnamed: U$3.RSH, U$3.TSH, U$4.2 (IN)
unnamed: C3.1, U1.RING (RIGHT)
OUTL: C7.1, U$1.I1.7 (7)
OUTR: C6.1, U$1.I1.8 (8)
SCL: U$1.ISCL (SCL), U$1.OSCL (SCL), U$2.6 (SCL)
SDA: U$1.ISDA (SDA), U$1.OSDA (SDA), U$2.5 (SDA)
V+: U$1.IVIN (VIN), U$1.OVIN (VIN)
VOL: R3.2, U$1.I1.1 (1)

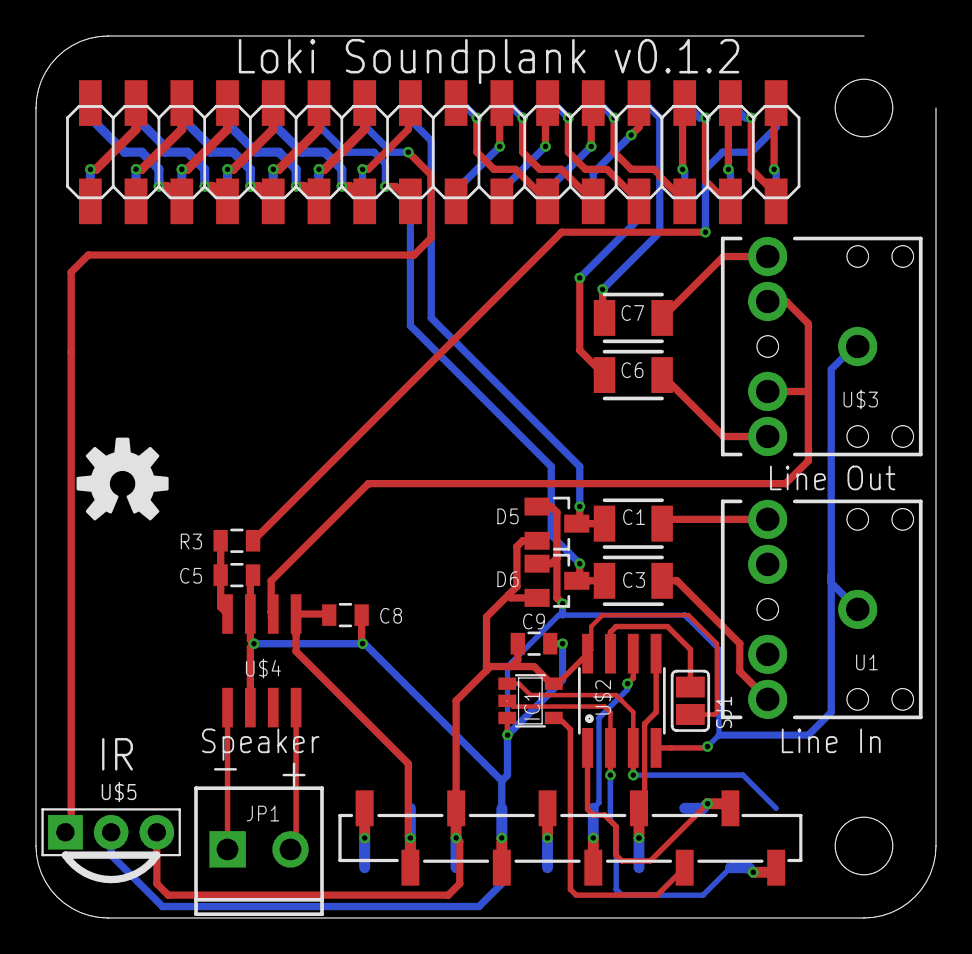
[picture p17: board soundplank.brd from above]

Board: 2 copper layers, 50.0 x 49.0 mm, 20 parts (0 on the bottom side), 52 nets.

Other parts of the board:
U$6: OSHW-LOGO-M

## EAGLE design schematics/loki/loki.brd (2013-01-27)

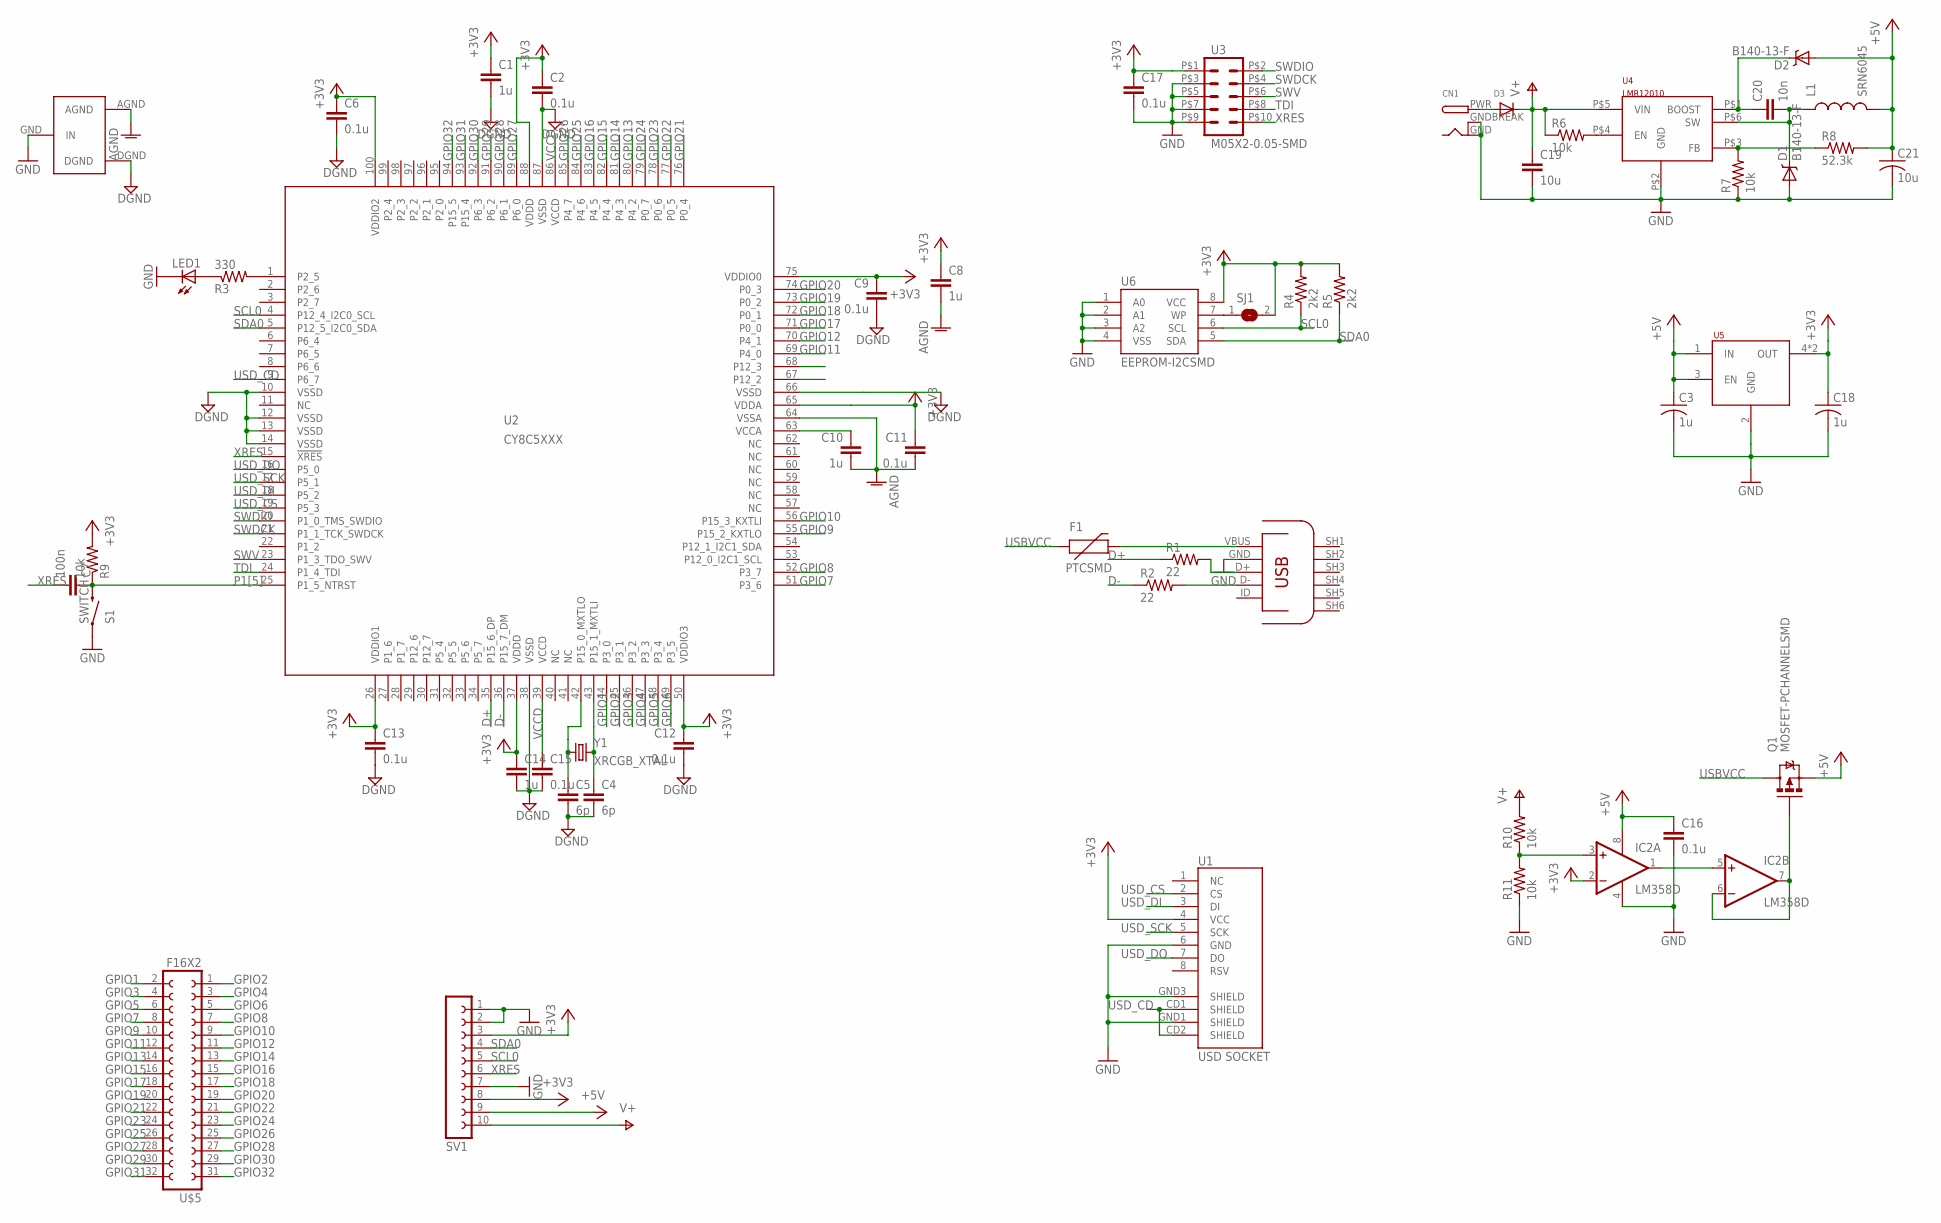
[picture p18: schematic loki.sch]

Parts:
C1, C8, C10, C14: 1u; C0603K
C2, C6, C9, C11, C12, C13, C15, C17: 0.1u; C0603K
C3, C18: 1u; C0603
C4, C5: 6p; C0603K
C7: 100n; C0603K
C16: 0.1u; 0603-CAP
C19: 10u; C1210
C20: 10n; C0805
C21: 10u; C1206
CN1: DCBARRELPTH; DCJACK_2MM_PTH
D1, D2: B140-13-F; SMA-DIODE
D3: DIODESMA; SMADIODE
F1: PTCSMD; PTC-1206
IC2: LM358D; SO08
L1: SRN6045
LED1: LEDCHIP-LED0805; CHIP-LED0805
Q1: MOSFET-PCHANNELSMD; SOT23-3
R1, R2: 22; 0603-RES
R3: 330; R0603
R4, R5: 2k2; R0603
R6, R7, R9, R10, R11: 10k; R0603
R8: 52.3k; R0603
S1: SWITCH; TACTILE_SWITCH_SMD
SJ1: SJ
SV1: FE10-1; FE10
U1: USD SOCKET; MICRO-SD-SOCKET-PP
U2: CY8C5XXX; TQFP-14X14-100
U3: M05X2-0.05-SMD; PINHD-2X5-0.05-SMD
U4: LMR12010; TSOT-6
U5: TLV702XX; SOT23-5
U6: EEPROM-I2CSMD; SO08
U7: MICROUSB; USB-MICROB
U$5: F16X2; FE16-2
U$9: GND_CONNECT; GNDCONNECT
Y1: XRCGB_XTAL; XRCGB-XTAL

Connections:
+3V3: C1.1, C2.1, C6.1, C8.1, C9.1, C11.1, C12.1, C13.1, C14.1, C17.1, C18.1, IC2.2 (-IN), R4.2, R5.2, R9.2, SJ1.2, SV1.3, SV1.8, U1.4 (VCC), U2.26 (VDDIO1), U2.37 (VDDD), U2.50 (VDDIO3), U2.65 (VDDA), U2.75 (VDDIO0), U2.88 (VDDD), U2.100 (VDDIO2), U3.P$1 (1), U5.4 (OUT), U5.5 (OUT), U6.8 (VCC)
+5V: C3.1, C16.1, C21.1, D2.A, IC2.8 (V+), L1.P$2 (2), Q1.2 (S), R8.2, SV1.9, U5.1 (IN), U5.3 (EN)
AGND: C8.2, C10.2, C11.2, U2.64 (VSSA), U$9.AGND
BOOST: C20.1, D2.C, U4.P$1 (BOOST)
CLKI: C4.1, U2.43 (P15_1_MXTLI), Y1.2
CLKO: C5.1, U2.42 (P15_0_MXTLO), Y1.1
D+: R1.1, U2.35 (P15_6_DP)
D+IN: R1.2, U7.D+
D-: R2.1, U2.36 (P15_7_DM)
D-IN: R2.2, U7.D-
DCIN: CN1.PWR, D3.A
DGND: C1.2, C2.2, C4.2, C5.2, C6.2, C9.2, C12.2, C13.2, C14.2, C15.2, U2.10 (VSSD), U2.12 (VSSD), U2.13 (VSSD), U2.14 (VSSD), U2.38 (VSSD), U2.66 (VSSD), U2.87 (VSSD), U$9.DGND
FB: R7.2, R8.1, U4.P$3 (FB)
GND: C3.2, C16.2, C17.2, C18.2, C19.2, C21.2, CN1.GND, CN1.GNDBREAK, D1.A, IC2.4 (V-), LED1.C, R7.1, R11.1, S1.1, SV1.1, SV1.2, SV1.7, U1.6 (GND), U1.GND1 (SHIELD), U1.GND3 (SHIELD), U3.P$3 (3), U3.P$5 (5), U3.P$7 (7), U3.P$9 (9), U4.P$2 (GND), U5.2 (GND), U6.1 (A0), U6.2 (A1), U6.3 (A2), U6.4 (VSS), U7.GND, U$9.GND (IN)
GPIO1: U2.44 (P3_0), U$5.2
GPIO2: U2.45 (P3_1), U$5.1
GPIO3: U2.46 (P3_2), U$5.4
GPIO4: U2.47 (P3_3), U$5.3
GPIO5: U2.48 (P3_4), U$5.6
GPIO6: U2.49 (P3_5), U$5.5
GPIO7: U2.51 (P3_6), U$5.8
GPIO8: U2.52 (P3_7), U$5.7
GPIO9: U2.55 (P15_2_KXTLO), U$5.10
GPIO10: U2.56 (P15_3_KXTLI), U$5.9
GPIO11: U2.69 (P4_0), U$5.12
GPIO12: U2.70 (P4_1), U$5.11
GPIO13: U2.80 (P4_2), U$5.14
GPIO14: U2.81 (P4_3), U$5.13
GPIO15: U2.82 (P4_4), U$5.16
GPIO16: U2.83 (P4_5), U$5.15
GPIO17: U2.71 (P0_0), U$5.18
GPIO18: U2.72 (P0_1), U$5.17
GPIO19: U2.73 (P0_2), U$5.20
GPIO20: U2.74 (P0_3), U$5.19
GPIO21: U2.76 (P0_4), U$5.22
GPIO22: U2.77 (P0_5), U$5.21
GPIO23: U2.78 (P0_6), U$5.24
GPIO24: U2.79 (P0_7), U$5.23
GPIO25: U2.84 (P4_6), U$5.26
GPIO26: U2.85 (P4_7), U$5.25
GPIO27: U2.89 (P6_0), U$5.28
GPIO28: U2.90 (P6_1), U$5.27
GPIO29: U2.91 (P6_2), U$5.30
GPIO30: U2.92 (P6_3), U$5.29
GPIO31: U2.93 (P15_4), U$5.32
GPIO32: U2.94 (P15_5), U$5.31
INDIN: C20.2, D1.C, L1.P$1 (1), U4.P$6 (SW)
unnamed: R3.2, U2.1 (P2_5)
unnamed: C10.1, U2.63 (VCCA)
unnamed: R6.2, U4.P$4 (EN)
unnamed: SJ1.1, U6.7 (WP)
unnamed: IC2.3 (+IN), R10.1, R11.2
unnamed: IC2.6 (-IN), IC2.7 (OUT), Q1.1 (G)
unnamed: IC2.1 (OUT), IC2.5 (+IN)
unnamed: LED1.A, R3.1
P1[5]: C7.1, R9.1, S1.3 (2), U2.25 (P1_5_NTRST)
SCL0: R4.1, SV1.5, U2.4 (P12_4_I2C0_SCL), U6.6 (SCL)
SDA0: R5.1, SV1.4, U2.5 (P12_5_I2C0_SDA), U6.5 (SDA)
SWDCK: U2.21 (P1_1_TCK_SWDCK), U3.P$4 (4)
SWDIO: U2.20 (P1_0_TMS_SWDIO), U3.P$2 (2)
SWV: U2.23 (P1_3_TDO_SWV), U3.P$6 (6)
TDI: U2.24 (P1_4_TDI), U3.P$8 (8)
USBVCC: F1.1, Q1.3 (D)
USD_CD: U1.CD1 (SHIELD), U1.CD2 (SHIELD), U2.9 (P6_7)
USD_CS: U1.2 (CS), U2.19 (P5_3)
USD_DI: U1.3 (DI), U2.18 (P5_2)
USD_DO: U1.7 (DO), U2.16 (P5_0)
USD_SCK: U1.5 (SCK), U2.17 (P5_1)
V+: C19.1, D3.C, R6.1, R10.2, SV1.10, U4.P$5 (VIN)
VBUS: F1.2, U7.VBUS (VCC)
VCCD: C15.1, U2.39 (VCCD), U2.86 (VCCD)
XRES: C7.2, SV1.6, U2.15 (!XRES!), U3.P$10 (10)

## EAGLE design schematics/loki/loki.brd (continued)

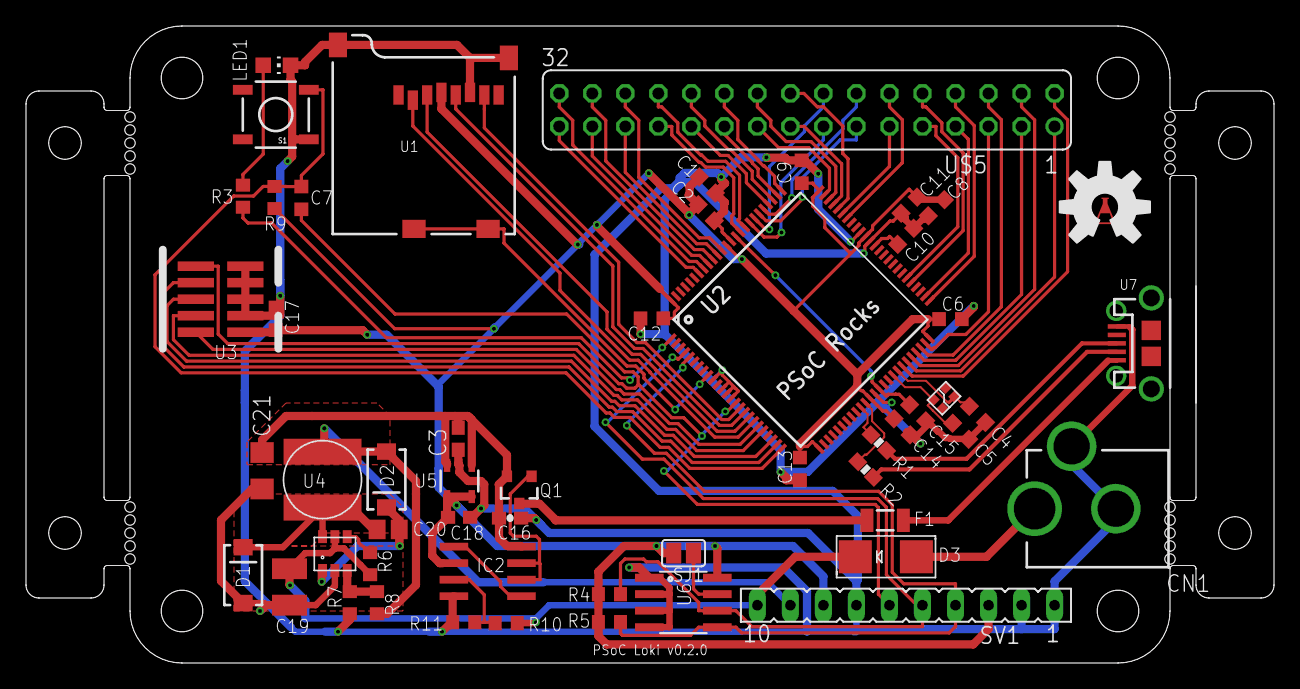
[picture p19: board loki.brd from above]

Board: 2 copper layers, 96.0 x 49.0 mm, 57 parts (1 on the bottom side), 72 nets.

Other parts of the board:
U$1: ARACHNID_LABS_LOGO_SM
U$6: LOKI_LOGO
U$12: OSHW-LOGO-L

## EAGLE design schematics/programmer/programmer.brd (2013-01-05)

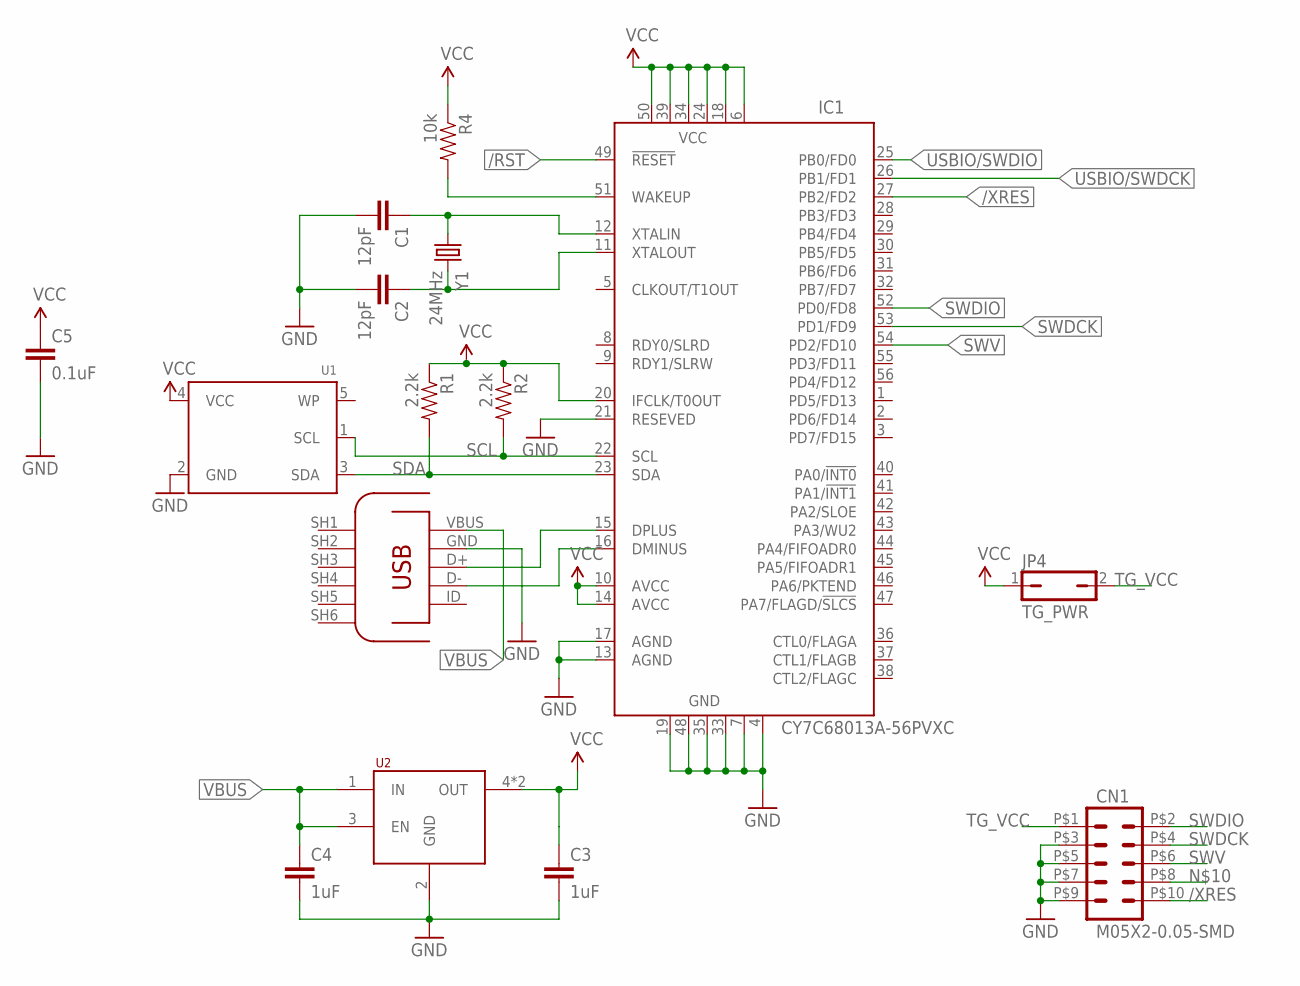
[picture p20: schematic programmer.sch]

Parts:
C1, C2: 12pF; 0805
C3, C4: 1uF; 0805
C5: 0.1uF; 0805
CN1: M05X2-0.05-SMD; PINHD-2X5-0.05-SMD
IC1: CY7C68013A-56PVXC; SSOP56
JP4: TG_PWR; JP1
R1, R2: 2.2k; 0805
R4: 10k; 0805
U1: EEPROM_I2C_MCP24AA32; SOT23-5
U2: TLV702XX; SOT23-5
U$3: MICROUSB; USB-MICROB
Y1: 24MHz; XRCGB-XTAL

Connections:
/RST: IC1.49 (!RESET)
/XRES: CN1.P$10 (10), IC1.27 (PB2/FD2)
GND: C1.2, C2.2, C3.2, C4.2, C5.2, CN1.P$3 (3), CN1.P$5 (5), CN1.P$7 (7), CN1.P$9 (9), IC1.4 (GND), IC1.7 (GND), IC1.13 (AGND), IC1.17 (AGND), IC1.19 (GND), IC1.21 (RESEVED), IC1.33 (GND), IC1.35 (GND), IC1.48 (GND), U1.2 (GND), U2.2 (GND), U$3.GND
unnamed: IC1.16 (DMINUS), U$3.D-
unnamed: IC1.15 (DPLUS), U$3.D+
unnamed: IC1.51 (WAKEUP), R4.2
SCL: IC1.22 (SCL), R2.2, U1.1 (SCL)
SDA: IC1.23 (SDA), R1.2, U1.3 (SDA)
SWDCK: CN1.P$4 (4), IC1.53 (PD1/FD9)
SWDIO: CN1.P$2 (2), IC1.52 (PD0/FD8)
SWV: CN1.P$6 (6), IC1.54 (PD2/FD10)
TG_VCC: CN1.P$1 (1), JP4.2
USBIO/SWDCK: IC1.26 (PB1/FD1)
USBIO/SWDIO: IC1.25 (PB0/FD0)
VBUS: C4.1, U2.1 (IN), U2.3 (EN), U$3.VBUS (VCC)
VCC: C3.1, C5.1, IC1.6 (VCC), IC1.10 (AVCC), IC1.14 (AVCC), IC1.18 (VCC), IC1.20 (IFCLK/T0OUT), IC1.24 (VCC), IC1.34 (VCC), IC1.39 (VCC), IC1.50 (VCC), JP4.1, R1.1, R2.1, R4.1, U1.4 (VCC), U2.4 (OUT), U2.5 (OUT)
XTALIN: C1.1, IC1.12 (XTALIN), Y1.1
XTALOUT: C2.1, IC1.11 (XTALOUT), Y1.2


Board: 2 copper layers, 40.0 x 25.0 mm, 16 parts (0 on the bottom side), 15 nets.

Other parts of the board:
U$1: OSHW-LOGO-S

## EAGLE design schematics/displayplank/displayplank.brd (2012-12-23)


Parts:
C1, C2: 0.1u; 0805
LED1, LED2, LED3, LED4: LEDSML0805; SML0805
Q1: MOSFET-NCHANNELSMD; SOT23-3
R1, R2, R3, R4: 340; 0805
R5: 100k; 0805
SJ1: SJ
U$1: LOKI_TOP_PLANKSHORT_NOHOLES; TOP_PLANK_SHORT_NOHOLES
U$2: EEPROM-I2CSMD; SO08
U$3: JOYSTICK-10MM
U$5: 5110-SCREEN

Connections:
+3V3: C1.1, SJ1.2, U$1.I+3V3 (+3V3), U$2.8 (VCC), U$5.P$4 (OSC), U$5.P$9 (VDD)
+5V: C2.1, R1.2, R2.2, R3.2, R4.2, U$1.I+5V (+5V)
A0: U$1.IA0 (A0), U$2.1 (A0)
A1: U$1.IA1 (A1), U$2.2 (A1)
A2: U$1.IA2 (A2), U$2.3 (A2)
D/C: U$1.I1.1 (1), U$5.P$6 (D/C)
GND: C1.2, C2.2, Q1.2 (S), R5.1, U$1.IGND (GND), U$2.4 (VSS), U$3.4 (GND), U$5.P$3 (GND), U$5.P$5 (SCE)
LIGHT: Q1.1 (G), R5.2, U$1.I1.5 (5)
unnamed: SJ1.1, U$2.7 (WP)
unnamed: LED1.A, R1.1
unnamed: LED2.A, R2.1
unnamed: LED3.A, R3.1
unnamed: LED4.A, R4.1
unnamed: LED1.C, LED2.C, LED3.C, LED4.C, Q1.3 (D)
unnamed: U$1.I2.4 (4), U$3.1 (UP)
unnamed: U$1.I2.2 (2), U$3.6 (CENTER)
unnamed: U$1.I2.3 (3), U$3.2 (LEFT)
unnamed: U$1.I2.5 (5), U$3.3 (DOWN)
unnamed: U$1.I2.1 (1), U$3.5 (RIGHT)
RES: U$1.I1.2 (2), U$5.P$1 (RST)
RST: U$1.IRST (RESET)
SCL: U$1.ISCL (SCL), U$2.6 (SCL)
SCLK: U$1.I1.3 (3), U$5.P$8 (SCLK)
SDA: U$1.ISDA (SDA), U$2.5 (SDA)
SDIN: U$1.I1.4 (4), U$5.P$7 (MOSI)
V+: U$1.IVIN (VIN)


Board: 2 copper layers, 50.0 x 49.0 mm, 18 parts (0 on the bottom side), 24 nets.

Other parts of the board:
U$4: OSHW-LOGO-M

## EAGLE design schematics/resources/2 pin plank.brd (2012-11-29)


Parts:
IC1: 74AHC1G86DBV; SOT23-5
SJ1: SJ
U$1: LOKI_PLANKLONG; PLANK_LONG
U$2: EEPROM-I2CSMD; SO08

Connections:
+3V3: IC1.5 (VCC), U$1.I+3V3 (+3V3), U$1.O+3V3 (+3V3), U$2.8 (VCC)
+5V: U$1.I+5V (+5V), U$1.O+5V (+5V)
A0: U$1.IA0 (A0), U$1.OA1 (A0), U$2.1 (A0)
A1: IC1.2 (I1), U$1.IA1 (A1), U$1.OA2 (A1), U$2.2 (A1)
A2: IC1.1 (I0), U$1.IA2 (A2), U$2.3 (A2)
AOUT: IC1.4 (O), U$1.OA0 (AOUT)
GND: IC1.3 (GND), SJ1.2, U$1.IGND (GND), U$1.OGND (GND), U$2.4 (VSS)
unnamed: U$1.I1.16 (16), U$1.O1.15 (15)
unnamed: U$1.I1.15 (15), U$1.O1.14 (14)
unnamed: U$1.I1.14 (14), U$1.O1.13 (13)
unnamed: U$1.I1.13 (13), U$1.O1.12 (12)
unnamed: U$1.I1.12 (12), U$1.O1.11 (11)
unnamed: U$1.I1.11 (11), U$1.O1.10 (10)
unnamed: U$1.I1.10 (10), U$1.O1.9 (9)
unnamed: U$1.I1.9 (9), U$1.O1.8 (8)
unnamed: U$1.I1.8 (8), U$1.O1.7 (7)
unnamed: U$1.I1.7 (7), U$1.O1.6 (6)
unnamed: U$1.I1.6 (6), U$1.O1.5 (5)
unnamed: U$1.I1.5 (5), U$1.O1.4 (4)
unnamed: U$1.I1.4 (4), U$1.O1.3 (3)
unnamed: U$1.I1.3 (3), U$1.O1.2 (2)
unnamed: U$1.I1.2 (2), U$1.O1.1 (1)
unnamed: U$1.I2.16 (16), U$1.O2.15 (15)
unnamed: U$1.I2.15 (15), U$1.O2.14 (14)
unnamed: U$1.I2.14 (14), U$1.O2.13 (13)
unnamed: U$1.I2.13 (13), U$1.O2.12 (12)
unnamed: U$1.I2.12 (12), U$1.O2.11 (11)
unnamed: U$1.I2.11 (11), U$1.O2.10 (10)
unnamed: U$1.I2.10 (10), U$1.O2.9 (9)
unnamed: U$1.I2.9 (9), U$1.O2.8 (8)
unnamed: U$1.I2.8 (8), U$1.O2.7 (7)
unnamed: U$1.I2.7 (7), U$1.O2.6 (6)
unnamed: U$1.I2.6 (6), U$1.O2.5 (5)
unnamed: U$1.I2.5 (5), U$1.O2.4 (4)
unnamed: U$1.I2.4 (4), U$1.O2.3 (3)
unnamed: U$1.I2.3 (3), U$1.O2.2 (2)
unnamed: U$1.I2.2 (2), U$1.O2.1 (1)
unnamed: SJ1.1, U$2.7 (WP)
unnamed: U$1.IRST (RESET), U$1.ORST (RESET)
SCL: U$1.ISCL (SCL), U$1.OSCL (SCL), U$2.6 (SCL)
SDA: U$1.ISDA (SDA), U$1.OSDA (SDA), U$2.5 (SDA)
V+: U$1.IVIN (VIN), U$1.OVIN (VIN)


Board: 2 copper layers, 80.0 x 49.0 mm, 4 parts (0 on the bottom side), 42 nets.

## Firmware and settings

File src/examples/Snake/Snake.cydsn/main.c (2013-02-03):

/* ========================================
 *
 * Copyright YOUR COMPANY, THE YEAR
 * All Rights Reserved
 * UNPUBLISHED, LICENSED SOFTWARE.
 *
 * CONFIDENTIAL AND PROPRIETARY INFORMATION
 * WHICH IS THE PROPERTY OF your company.
 *
 * ========================================
*/
#include <device.h>

void main()
{
    /* Place your initialization/startup code here (e.g. MyInst_Start()) */

    /* CyGlobalIntEnable; */ /* Uncomment this line to enable global interrupts. */
    for(;;)
    {
        /* Place your application code here. */
    }
}

/* [] END OF FILE */

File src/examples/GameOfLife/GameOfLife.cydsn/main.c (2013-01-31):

/* ========================================
 *
 * Copyright YOUR COMPANY, THE YEAR
 * All Rights Reserved
 * UNPUBLISHED, LICENSED SOFTWARE.
 *
 * CONFIDENTIAL AND PROPRIETARY INFORMATION
 * WHICH IS THE PROPERTY OF your company.
 *
 * ========================================
*/
#include <device.h>
#include <stdlib.h>

#define GET_CELL(grid, x, y) (((grid)[(x)*6+(y)/8] >> ((y) & 0x7)) & 1)
#define SET_CELL(grid, x, y) (grid)[(x)*6+(y)/8] |= 1 << ((y) & 0x7)
#define CLEAR_CELL(grid, x, y) (grid)[(x)*6+(y)/8] &= ~(1 << ((y) & 0x7))

#define WIDTH 84
#define HEIGHT 48
#define MUTATION_RATE 2663050

int count_live(uint8 *grid, int x, int y) {
    int dx, dy, ret=0;
    for(dx = -1; dx < 2; dx++) {
        for(dy = -1; dy < 2; dy++) {
            if(dx == 0 && dy == 0) continue;
            ret += GET_CELL(grid, (x + dx + WIDTH) % WIDTH, (y + dy + HEIGHT) % HEIGHT);
        }
    }
    return ret;
}

void main()
{
    LCD_1_buffer buf1, buf2;
    LCD_1_buffer *current=&buf1, *next=&buf2, *tmp;
    int seed;
    int x, y, i, num;
    
    PrISM_1_Start();
    LCD_1_Start();
    CySetTemp();

    /* Read in the seed value */
    seed = CY_GET_REG32(CYDEV_EE_BASE);
    srand(seed);

    CyGlobalIntEnable; /* Uncomment this line to enable global interrupts. */

    // Initialize the board with random data
    for(i = 0; i < 504; i++)
        current->data[i] = (uint8)rand();
    
    // Write out a new seed
    seed = rand();
    EEPROM_1_Write(&seed, 0);
    
    for(;;)
    {
        for(x = 0; x < 84; x++) {
            for(y = 0; y < 48; y++) {
                if(rand() < MUTATION_RATE) {
                    SET_CELL(next->data, x, y);
                    continue;
                }
                num = count_live(current->data, x, y);
                if(num < 2 || num > 3) {
                    CLEAR_CELL(next->data, x, y);
                } else if(GET_CELL(current->data, x, y) || num == 3) {
                    SET_CELL(next->data, x, y);
                } else {
                    CLEAR_CELL(next->data, x, y);
                }
            }
        }
        tmp = next;
        next = current;
        current = tmp;
        
        LCD_1_Update(current);
    }
}

/* [] END OF FILE */

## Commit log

2012-11-29 Minor layout changes; improvements to 2 pin plank template.
    [2 pin plank.brd, loki.brd, loki.sch]
2012-11-29 Added reverse polarity protection diode.
    [loki.brd, loki.sch]
2012-11-30 Added protoplank and 8 pin plank template.
    [8 pin plank.brd, 8 pin plank.sch, protoplank.brd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]
2012-12-01 Updated protoplank to use square pads for ease of SMT soldering.
    [protoplank.brd, protoplank.sch]
2012-12-01 Added decoupling capacitors to the protoboard.
    [protoplank.brd, protoplank.sch]
2012-12-01 Added first revision of motor plank, 6 pin plank template.
    [6 pin plank.brd, 6 pin plank.sch, motorplank.brd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]
2012-12-01 Added schematics and drawings for motor plank.
2012-12-01 Text should be on a text layer, not in copper.
    [motorplank.brd]
2012-12-01 Add LED indicators for motor outputs.
    [motorplank.brd, motorplank.sch]
2012-12-01 Increase isolation on top ground plane.
    [motorplank.brd]
2012-12-01 Move capacitors to the side closer to ground.
    [motorplank.brd]
2012-12-02 Added display plank; top plank sample.
    [displayplank.brd, displayplank.sch, top plank.brd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]
2012-12-02 Replace usb mini connector with usb micro one.
    [displayplank.brd, loki.brd, loki.sch]
2012-12-02 Widened a few traces where possible.
    [loki.brd, loki.sch]
2012-12-02 Added tripads for edge connectors on protoshield.
    [protoplank.brd, protoplank.sch]
2012-12-02 Minor positioning tweak.
    [motorplank.brd]
2012-12-02 Updated images.
    [loki.brd, loki.sch]
2012-12-02 Reorganized repository.
    [2 pin plank.brd, 2 pin plank.sch, 6 pin plank.brd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]
2012-12-03 Tweaks to planks; change 0604 parts for 0805 where possible
    Also added 4 pin plank; minor text changes.
    [4 pin plank.brd, 4 pin plank.sch, displayplank.brd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]
2012-12-05 Misc tweaks, generated gerbers.
    [displayplank.GBP, displayplank.back.gbl, displayplank.backmask.gbs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]
2012-12-06 Added soundplank.
    [soundplank.brd, soundplank.sch]
2012-12-07 Improved soundplank labelling; generated gerbers.
    [soundplank.brd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]
2012-12-09 Updated soundplank to make use of opamp outputs when on the bottom.
    [soundplank.brd, soundplank.sch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]
2012-12-10 Fix footprints on the soundplank so they're not backwards (oops!)
    [soundplank.brd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]
2012-12-13 Updated loki stencil
    [loki.brd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]
2012-12-16 Improve audio routing for line out.
    [soundplank.brd]
2012-12-23 Displayplank: Added pulldown for FET, improved capacitor spacing, fixed layer of name text.
    [displayplank.brd, displayplank.sch]
2012-12-29 Reworked Loki to fit the 100TQFP package.
    [loki.brd, loki.sch]
2012-12-29 Misc fixes.
    [loki.brd]
2012-12-31 Misc layout improvements to Loki; updated to v0.2.
    [loki.brd, loki.sch]
2013-01-01 Added schematic for PSoC programmer.
    [programmer.brd, programmer.sch]
2013-01-01 Added missing board file from previous commit.
    [loki.brd]
2013-01-01 Added missing gerbers and loki schematic
    [loki.GBP, loki.back.gbl, loki.backmask.gbs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]
2013-01-05 Fixed both Loki and the programmer to use 3.3v for power on programming headers.
    [loki.brd, loki.sch, programmer.brd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]
2013-01-13 Layout tweaks to motor plank.
    [motorplank.brd, motorplank.sch]
2013-01-27 Implemented bootloader host.
    [loki.brd]
2013-01-27 Fix write protect pullups on plank EEPROMs.
    [protoplank.brd, protoplank.sch, soundplank.brd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]
2013-01-31 Added first demo app (game of life) and library code for the Nokia display.
    [currentplank.brd, currentplank.sch]
2013-02-02 Work on constant current plank.
    [currentplank.brd, currentplank.sch]
2013-02-03 Rework of current plank, now using opamp and trimpot to set current limit.
    [currentplank.brd, currentplank.sch]
2013-02-03 Thermal vias etc for current plank.
    [currentplank.brd, currentplank.sch]
2013-02-03 Moar symmetry!
    [currentplank.brd]
2013-02-04 Updates to current plank silkscreen etc.
    [currentplank.brd, currentplank.sch]
2013-02-10 Added logo to Current Plank, generated gerbers.
    [currentplank.brd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]
2013-02-10 Created new Shield Plank.
    [shieldplank.brd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]
2013-02-10 Added ground pour; regenerated gerbers; generated images.
    [shieldplank.brd, shieldplank.sch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]
2013-02-12 Fixed top right corner missing in board outline
2013-04-08 Tweaks to shield and current planks.
    [currentplank.back.gbl, currentplank.backmask.gbs, currentplank.backsilk.gbo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]

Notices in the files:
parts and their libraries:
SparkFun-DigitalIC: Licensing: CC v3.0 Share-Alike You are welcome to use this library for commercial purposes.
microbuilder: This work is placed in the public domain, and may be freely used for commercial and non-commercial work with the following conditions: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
